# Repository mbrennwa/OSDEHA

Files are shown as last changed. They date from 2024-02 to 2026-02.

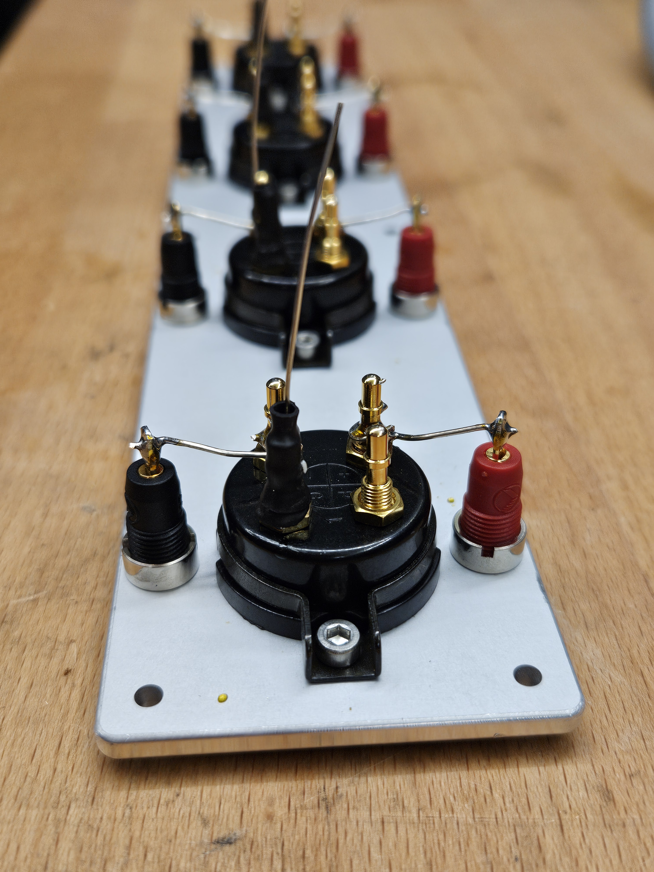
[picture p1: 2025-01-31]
photos/subchassis_underside_sockets1.jpg

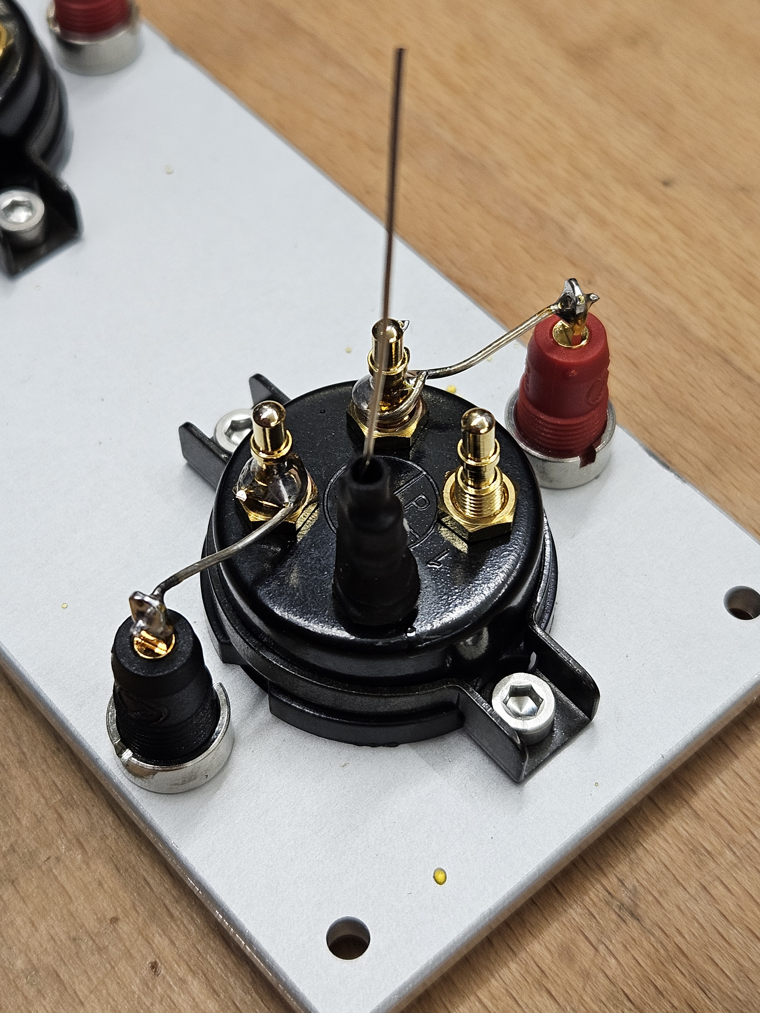
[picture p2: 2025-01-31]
photos/subchassis_underside_sockets2.jpg

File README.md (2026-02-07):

# Open-Source Directly-Heated Triode Electrostatic Headphone Amplifier (OSDEHA)

The OSDEHA is an open-hardware electrostatic headphone amplifier based on directly heated triodes (DHTs).  
It is designed for DIY builders who value simplicity, transparency, and full access to the underlying circuit and mechanical design.

The project is developed openly, with design discussion and iteration happening in the DIY audio community. All design files required to manufacture and assemble the amplifier are provided.

⚠️ **Warning:** This project involves lethal voltages. Do not attempt to build or operate this amplifier unless you understand and respect high-voltage safety practices.

## Documentation & Discussion

- Project homepage:  
  https://mbrennwa.github.io/OSDEHA/

- Design discussion and build feedback:  
  https://www.diyaudio.com/community/threads/open-source-dht-estat-headphone-amp-osdeha.407679/

## License

This project is licensed under the **CERN Open Hardware Licence v2 – Strongly Reciprocal (CERN-OHL-S-2.0)**.

You are free to:
- Study the design  
- Build the hardware  
- Modify and redistribute it  

Under the condition that **derivative works remain open under the same license**.

**Any physical implementation of this design must carry a visible license notice on the outside of the amplifier enclosure**, as required by the CERN-OHL-S-2.0.

See `LICENSE.txt` for details.

## Acknowledgements

Thanks to the diyAudio community for discussion, testing, and feedback during development.

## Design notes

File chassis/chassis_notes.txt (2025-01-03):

Concept:
- 2 chassis (1 x amplifier, 1 x power supply):
	- allows acceptable form factor for amplifier module, while PSU can be hidden away (but PSU can also be stacked underneath the amp).
	- Keep recitifier noise away from amplifier
	- use same footprint (and height?) for both chassis, so they can nicely be stacked or placed next to each other
- Amp dimensions (external, without front plate):
	- width = 280 mm (including 2 x 40 mm width of heatsinks on the sides)
	- height = 100 mm [height not including the power tubes sticking out from the top]
	- depth = 300 mm
- PSU dimensions (external, without front plate):
	- width = 280 mm
	- height = 100 mm [height of large PSU caps 82 mm from PCB]
	- depth = 300 mm
- Connections between PSU and amp:
	- 1 x cable for HV PSU + bias (keep separate from potentially noisy heater / filament RAW DC currents)
	- 1 x cable heater and RAW-DC filament currents (1 x 6.3 VDC for input heaters, 2 x RAW-DC supplies for Coleman Filament regs in the amp chassis)
	- only PSU: IEC mains inlet + switch + fuses
	- only amp: 2 x XLR audio inputs, Stax outputs on frontpanel

Heatsinks for amp:
	- dimensions: 40 x 300 mm x 100 mm
	- Fischer SK 56 100 SA or SK 501 100 SA

PSU inernal arrangement
	- Left: 2 x mains transformers
	- Center: 1 x main PSU board (HV + 6.3 V heater + HV bias)
	- Right: 2 x filament RAW-DC supplies

PSU front panel:
	- Power LED indicator at center

PSU rear panel:
	- IEC mains inlet (incl. switch + fuses), on the side where the mains transformers are
	- 2 x cable connectors to amp chassis

Amp internal arrangment:
	- Heasinks on left and right
	- 2 x amp board on heatsinks.
	  Right board aligned to front plate
	  Left board aligned to rear plate (to keep input tubes away from front plate, make space for Stax connector on front plate)
	- Coleman boards:
	  2 x boards on right, aligned to rear plate
	- 2 x boards boards on left, aligned to front plate (Stax connector on front plate can mount above the Coleman boards)
	- 4 x power tubes between the amp boards, centered on a line in the middle of the chassis. Tubes sticking out on top of the chassis, mounted on small subchassis

Amp front panel:
	- Volume control on right (above right amp board)
	- Stax connector on left (above Coleman regs)
	- Power LED indicator at center

Amp rear panel:
	- 2 x cable connectors to amp chassis
	- 2 x XLR audio inputs

Cable connections between PSU and amp chassis:

	Cable I (high voltage lines):
	- B+
	- B-
	- B2-
	- 580 VDC bias
	- GND
	- Earth/chassis

	Cable II (heater/filament RAW-DC):
	- Heater POS (6.3 V)
	- Heater NEG (0 V) [connected to GND on PSU main board]
	- RAW-DC 1 POS [floating]
	- RAW-DC 1 NEG [floating]
	- RAW-DC 2 POS [floating]
	- RAW-DC 2 NEG [floating]
	cable clamp: 206966-7

	Connector requirements:
	- Use different connectors for the two cables to avoid accidental mixups!
	- PE/chassis connection:
		- PE conncetions on HV cable, not on Filament cable
		- PE/chassis pin on the HV cable must connect before the other pins
	- All connectors must be rated for 600 VDC or more (filament supplies are floating on B- voltage!)
	
	--> Connector HV-Cable: Amphenol DMS 18-8
	    700 V or higher rating
	    center pin is larger/longer, use this for PE -- use extra pins for parallel connections: 2 x PE and 2 x GND between pos and neg HV pins
	    Cable male:     MS3106E18-8P
	    Cable female:   MS3106E18-8S
	    Chassis male:   MS3102E18-8P
	    Chassis female: MS3102E18-8S

	--> Connector Heater/filament cable: DMS 18-12
	    Cable male:     MS3106E18-12P
	    Cable female:   MS3106E18-12S
	    Chassis male:   MS3102E18-12P
	    Chassis female: MS3102E18-12S
	    
	Cable: Lapp 301606S‎, 6 conductors 16 AWG, color coded, shielded

Old notes, but may be worth to keep:

Ideas and thoughts
	- DON'T (EITHER UGLY OR DOES NOT FIT, WILL NEED MACHINING FOR HOLES/PLUGS/VOLUME-KNOB -- FRONTPANEL DESIGN IS EASIER!) Use ready made chassis (19zoll.com, modushop, etc.) or go with separate heatsinks + Schaeffer panels?
	- amp boards on the sides, flat on bottom plate, transistors on heatsinks
	- transformers on the back, on bottom plate (or on rear plate?), between the amp boards
	- PSU boards on the bottom plate, just behind the front plate.
	- RAW DC supply for Coleman regs on rear panel?
	- 4 x power DHTs mounted on sub-chassis above PSU board / transformers
	- Coleman regs near the DHTs on the subchassis for accessibility to adjust filament voltages?
	  ALTERNATIVE: Coleman regs on bottom plate, between amp boards (either near rear or front panel) / 2 Colemans ons left and 2 Colemans on right
	- IEC mains inlet on the rear plate, left side
	- Audio XLR inputs on the rear plate, right side
	- Volume pot (4 channel for balanced/stereo): centered or on the right (away from mains inlet)? Mount pot on subchassis used for DHT output tubes? Use extension rod to the button on the front panel 
	- Headphone jack(s) on front panel, location depending on position of volume control
	- Power indicator LED on front panel, driven by heater supply
	- Front plate covers heat sinks on the sides, plate fixed by four screws into the front edges of the heatsinks (cut threads into heatsinks)
	- Heatsinks fixed to bottom plate with screws, theads cut into lower edge of heatsinks
	- Top and rear plates mounted in between the heatsinks using square alu rods as connectors (about 10x10mm)
	  (top plate connects to the heatsinks, with threaded holes in heatsinks)
	  (reat plate connects to bottom and top plates, so less work messing around with cutting threads in heasinks)

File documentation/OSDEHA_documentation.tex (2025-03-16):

\input{doc_preamble}

\title{The Open-Source Directly-Heated Triode \\ Electrostatic Headphone Amplifier \\ (OSDEHA)}
\author{Matthias Brennwald}
\date{THIS DOCUMENT IS UNDER CONSTRUCTION!\\ Draft Version \today}

\begin{document}

% \twocolumn[\maketitle]

\maketitle

\emph{Warning: This DIY project involves high voltage. Individuals utilizing the information provided must possess expert knowledge, adhere to stringent safety precautions, and assume full responsibility for all associated risks. The authors and contributors of this project expressly disclaim any liability for injuries or damages arising from the use or misuse of this information.}

\clearpage

\tableofcontents

\clearpage

\section{Overview}

This document describes an audio amplifier for electrostatic headphones. The design of the amplifier is targeted at DIY builders and is published as open hardware (see \secn{license}).

Electrostatic headphones operate on audio signals characterized by high voltage and low current. This is the domain of vacuum tubes, making them most suitable as drivers for electrostatic headphones.  While there exist a number of tube amplifiers for electrostatic headphones, many of these designs do not utilize directly-heated triodes (DHTs), which exhibit outstanding linearity and sound quality.\par

The OSDEHA uses DHT tubes for its output stage and implements the following design goals:
\begin{itemize}
\item The audio output is taken directly from the anodes of the DHT output tubes. There are no transformer or capacitors to transfer the power to the headphones.
\item The amplifier input takes balanced input at signal levels of modern audio sources (mostly DACs these days).
\item The design prioritizes the quality of audio reproduction and electronic design rather than on low cost.
\item The amplifier should be reasonably compact. The power supply unit may be a separate unit to keep the amplifier unit reasonable compact.
\end{itemize}

The OSDEHA design files, along with supporting documents and data, are available in the OSDEHA file repository\cite{osdeha_github}.

There is a public discussion thread of the OSDEHA at diyAudio\cite{osdeha_p1}. 

\section{Amplifier Design}

\subsection{Driving Electrostatic Headphones} \seclabel{estat_drive}

Electrostatic headphones operate using three electrodes: two fixed outer electrodes (stators) and a movable central electrode (diaphragm). The diaphragm is biased at a high voltage relative to the stators. The audio signal is applied to the stators in opposite polarities, generating an electric field that controls the movement of the charged diaphragm. For accurate sound reproduction, the electrostatic forces acting on the diaphragm must be proportional to the applied audio signal. To prevent distortion of the audio output, the charge on the diaphragm must remain constant.

The electrical impedance of electrostatic headphones is primarily determined by the capacitance of the two stators, which is typically around \SI{100}{pF}\cite{osdeha_p3}.

The voltage swing required to drive the stators depends on the headphone sensitivity and the desired sound pressure level. An experiment using various genres of well-recorded music indicated that an undistorted \SI{1.3}{kV} peak-to-peak swing of the bipolar output is desirable (i.e., \SI{650}{\unitVpp} at each stator)\cite{osdeha_p8}. The corresponding current swing measured in this experiment was approximately \SI{4}{mA}. However, driving the \SI{100}{pF} load to full output at frequencies up to \SI{20}{kHz} and beyond necessitates larger peak currents, around \SI{20}{mA}\cite{osdeha_p2}.

\subsection{Output Stage}\seclabel{outputstage}

\figr{OPS_concept} illustrates the conceptual layout of the OSDEHA. The output stage employs two DHTs in a push-pull configuration to deliver the symmetric, bipolar output required to drive electrostatic headphones. For efficient audio power transfer to the headphones, the AC impedance of the anode loads must be much larger that that of the headphones (several \unit{M\Ohm}). This cannot be achieved using passive anode-load resistors; instead, active constant-current sources (CCSs) are employed. The CCS loads not only enhance the amplifier's linearity and voltage gain but also suppress ripple and noise from the B+ rails.

\begin{figure}
\begin{center}

\caption{Conceptual layout of the OSDEHA: differential input and gain stage, push-pull DHT output stage.}
\figlabel{OPS_concept}
\end{center}
\end{figure}

The choice of output tube type is dictated by the drive requirements of the headphones, as described in \secn{estat_drive}. Since the two tubes are connected in series with the headphones, each tube is responsible for half of the total voltage swing. Thus, each tube must handle a swing of \SI{\pm325}{V} at a \SI{20}{mA} bias. Furthermore, to emphasize the characteristic ``DHT sound,'' the DHT output stage should contribute as much voltage gain as possible to the overall amplifier gain.

Several DHT tube types were evaluated for the OSDEHA\cite{osdeha_p9,osdeha_whichDHT}. Specifically:

\begin{itemize}
\item The 841/VT-51 tube offers a gain of 30$\times$ and can be biased up to \SI{425}{V}. However, at the operating point required for the OSDEHA, the 841 tends to operate with a positive grid voltage, leading to grid current draw. Additionally, these tubes are relatively scarce.
\item The 20B tube is a modern design with a gain of 20$\times$ and supports biasing up to approximately \SI{500}{V}. However, these tubes are quite large (roughly the size of a beer bottle) and are produced only in small quantities by a single manufacturer (Emissionlabs), raising concerns about their long-term availability.
\item The family of the 801/801A/VT-62 and 10Y/VT-25 types\cite{aasyl_801types} provide a gain of 8$\times$. The 801 can be biased up to \SI{500}{V}, while the 10Y should not be biased above \SI{450}{V}. These tubes are available as new-old-stock and from new production.
\end{itemize}

From a technical perspective, the high gain of the 20B makes it an attractive option. However, due to concerns about the long-term availability of the 20B, the 801/10Y family of tubes is deemed a more practical choice for the OSDEHA design.

\figr{801A_curves} illustrates the characteristic curves measured from the 801A tube (with the 10Y/VT-25 being equivalent) along with the load line of a \SI{20}{mA} constant-current source (CCS). The anode DC bias is set to \SI{420}{V}, corresponding to a grid bias of approximately \SI{-34}{V}. This bias point allows for an anode voltage swing of \SI{\pm325}{V} within the tube's linear operating range. The grid voltage remains below +\SI{10}{V}, where measured grid current stays well under \SI{1}{mA}. With the anode voltage approaching ground potential, the B- voltage is set to \SI{-420}{V} and the B+ voltage to \SI{+420}{V}, maintaining symmetry.

\begin{figure}
\begin{center}

\caption{Characteristic curves of the 801A DHT, showing a DC bias point at \SI{420}{V} and \SI{20}{mA}, with a constant-current load line allowing an anode swing of \SI{\pm325}{V} (blue).}
\figlabel{801A_curves}
\end{center}
\end{figure}

\figr{activeload_concept} shows the simplified circuit of the CCSs used to load the anodes of the DHT output tubes. This circuit functions as a CCS in the audio/AC domain while providing a fixed voltage in the DC domain. In both cases, the FET Q1 controls the circuit's output to the anode. The depletion-mode FET Q2 drops most of the voltage from B+ and isolates Q1 from any noise or ripple present in the B+ supply.\par

\begin{figure}
\begin{center}

\caption{Simplified circuit of the active load (AC-coupled CCS).}
\figlabel{activeload_concept}
\end{center}
\end{figure}

In the audio/AC domain, the gate of Q1 is connected to the anode through capacitor C. Q1 mirrors any AC variation in the anode voltage from its gate to its source pin. This configuration maintains a constant voltage between the source of Q1 and the DHT anode, thereby ensuring a constant current through R2. If the headphone stator is driven directly by the DHT anode (output 1 in \figr{activeload_concept}), this current is shared between the DHT and the stator. Consequently, the current flowing through the DHT will exhibit slight variations in response to the AC current consumed by the stator. These variations are typically less than \SI{4}{mA}\cite{osdeha_p8}, which is significantly smaller than the DC bias current. As a result, the load line seen by the DHT anode will closely resemble the one shown in \figr{801A_curves}, although it may not be perfectly flat. Alternatively, the stator can be connected to the $\mu$-output (output 2 in \figr{activeload_concept}) instead of taking the audio output directly from the DHT anode. In this $\mu$-follower configuration\cite{pimm_ccs,kimmel_mustage}, the stator draws its current directly from Q1 rather than through R2. This restores the constant-current operation of the DHT tube and produces a flat load line as shown in \figr{801A_curves}. The value of R2 is typically chosen as a compromise between maximizing the impedance of the CCS load and minimizing the voltage drop (and heat dissipation) across R2\cite{muresistorvalue}.

In the DC domain, the gate of FET Q1 is grounded through R1, fixing the source pin at $-V_{\rm GS,0}$. This arrangement biases the anode at a slightly negative DC voltage determined by $V_{\rm GS,0}$ and the DC voltage drop across R2. As a result, the amplifier outputs maintain a stable DC voltage, effectively compensating for any thermal drift or aging of the DHT tubes.

\subsection{Input Stage}\seclabel{inputstage}

The primary function of the input stage is to amplify the balanced input signal ($2 \times \SI{3.5}{\unitVpp}$) to a level sufficient to drive the DHT grids ($2 \times \SI{86}{\unitVpp}$). This requires a voltage gain of $86 / 3.5 = 25\times$.

Following the lines of the output stage, the differential input stage is designed as long-tailed pair (LTP)\cite{valvewizard_LTP} utilizing tubes with triode characteristics. To maximize the linearity and voltage gain of the LTP, the ``tail'' is configured as a constant-current source (CCS), as illustrated in \figr{IPS_concept}.

\begin{figure}
\begin{center}

\caption{Simplified circuit of the input stage.}
\figlabel{IPS_concept}
\end{center}
\end{figure}

A triode-connected 6E5P tube provides suitable gain and exhibits very linear amplification\cite{bartola_thdbenchmark,osdeha_p33}. Each 6E5P is biased at \SI{10}{mA} with an anode-to-cathode voltage of \SI{170}{V} and a \SI{25}{k\Ohm} load resistor, providing more than \SI{\pm100}{V} of anode AC swing (\figr{6E5P_curves}).

\begin{figure}
\begin{center}

\caption{Characteristic curves of a triode-connected 6E5P tube, showing a \SI{25}{k\Ohm} load line with DC bias at \SI{170}{V} and \SI{10}{mA}.}
\figlabel{6E5P_curves}
\end{center}
\end{figure}

The LTP input stage is capacitor-coupled to the grids of the output DHTs. A properly chosen capacitor does not introduce measurable distortion to the audio signal\cite{bateman_caps_distortion}, provided there is no significant current flow across it\cite{aiken_farting_out}. To ensure stable biasing, the DHT grids are driven by FETs configured as source followers. The DC bias voltage for the DHT output tubes is applied to the gates of these FETs, ensuring stable operation even when the DHT grids are driven into grid current.

\section{Power Supplies}

\subsection{High-Voltage Supplies (B+, B-, B2-)}
The amplifier's input and output stages operate on a bipolar high-voltage supply (B+ and B- rails). Additionally, the DHT grids require a bias voltage more negative than B-, necessitating an additional B2- supply. All three high-voltage supplies utilize the same circuit design to deliver clean and stable voltage outputs (\figr{HV_PSU_simple}). The circuits are deliberately designed without feedback-based voltage regulation, as such feedback loops are often associated with sound degradation. A full-wave rectifier and smoothing capacitor (C1) generate a raw DC voltage. This raw supply feeds a current source that injects a small, constant current into R1 and C1. Once C1 is fully charged after startup, R1 develops a constant voltage drop, which serves as a reference mirrored to the voltage output across the DC+ and DC- terminals. For the B+ supply, the DC- output is referenced to GND, while the B- and B2- supplies have their DC+ terminals at GND.

\begin{figure}
\begin{center}

\caption{Simplified circuit of the high-voltage power supplies.}
\figlabel{HV_PSU_simple}
\end{center}
\end{figure}

To prevent audio noise during startup and reduce stress on the tubes, the high-voltage supplies are activated only after the tubes have warmed up for a few seconds. This delay is implemented using a relay switch controlled by a timer triggered by the heater supply.

\subsection{Diaphragm Bias Voltage}
High-performance electrostatic headphones typically require a \SI{580}{V} DC bias voltage for the diaphragm. The current output of the bias voltage supply is negligible. A charge pump riding on the B+ rail and its AC supply is used to charge a string of capacitors, with their voltage limited to the intended bias level by a string of Zener diodes in parallel to the capacitors. It is crucial to maintain the \emph{charge} on the diaphragm, rather than the diaphragm voltage. To this end, a high-ohmic current-limiting resistor is inserted in the output of the bias supply.

\subsection{Heater Supply for the Input-Stage Tubes}
The heaters of the input-stage tubes are powered by a clean DC voltage to prevent crosstalk of hum or noise from the heater supply into the audio signal. This DC supply is implemented using a standard three-pin voltage regulator chip.

\subsection{DHT Filament Supply}
Like the input-stage heaters, the DHT filaments are powered by DC. However, in DHTs, the filament also serves as the cathode and is part of the audio circuit. During audio playback, a small signal voltage develops across the filament terminals. To prevent the DC filament supply from interfering with this AC signal, it is preferable to control the filament supply current rather than the voltage. This is accomplished using the Coleman Regulator\cite{ColemanDTHFilReg}. The OSDEHA utilizes four Coleman Regulator V9 boards (one per DHT). In each amplifier channel, a single raw DC supply can power a pair of V9 boards.

\section{Putting the Pieces Together}

\figr{system_overview} provides an overview of the various OSDEHA units and their interconnections. The units are distributed across two chassis: one for the power supply and another for the amplifier.

\begin{figure}
\begin{center}

\caption{Overview of the OSDEHA units and their connections (see text).}
\figlabel{system_overview}
\end{center}
\end{figure}

Power-supply chassis:
\begin{itemize}
\item IEC mains inlet with a power switch and mains fuses
\item Two mains transformers
\item Main power-supply board providing stabilized DC voltages for B+, B-, B2-, diaphragm bias, and the heaters of the input-stage tubes
\item Two boards supplying raw DC to the Coleman DHT filament regulators
\end{itemize}

Amplifier chassis:
\begin{itemize}
\item Two amplifier main boards (left and right channels)
\item Four DHT power tubes (two per channel)
\item Four Coleman DHT filament regulators
\item Two XLR audio input sockets
\item Stereo balanced volume control
\item Stax headphone output socket
\end{itemize}

The two chassis are interconnected by two umbilical cables, U1 and U2. U1 carries the high-voltage, low-current supplies (B+, B-, B2-, GND) and provides the chassis-to-earth connection. U2 carries the low-voltage, high-current supplies for the heaters of the input-stage tubes and the Coleman DHT filament regulators.

\section{Mechanical construction}

HEATSINKS, CHASSIS, ETC.

UMBILICALS BETWEEN PSU AND AMP CHASSIS in \figr{power_pinouts}.

\begin{figure}
\begin{center}

\caption{Pinout of the power umbilical connections between the power supply and amplifier chassis.}
\figlabel{power_pinouts}
\end{center}
\end{figure}

\section{Build Notes, Bring-Up, and Initial Adjustments}

The process of building, testing, and adjusting the OSDEHA is best carried out step by step, as outlined below. Use a variac to gradually ramp up mains power while bringing up the circuits. Turn off the power supply and set the variac output to zero before each step. Before working on the circuits, always ensure that no dangerous voltages remain present (e.g., all capacitors are discharged, and the mains cable is disconnected).

\subsection{Power Supply}
\begin{itemize}
\item Assemble the power-supply chassis and boards. Install the boards, sockets, and transformers in the power-supply chassis. Wire the primary windings of the transformers to the mains inlet and power switch in the chassis. Wire the power supply outputs to the umbilical sockets.
\item Confirm proper connection of all metal parts of the power-supply chassis to mains earth.
\item Wire the transformer secondaries for the heater supply. Switch on the power supply and gradually ramp up mains power using the variac. Confirm that the heater supply functions as expected. Verify the operation of the high-voltage delay relay.
\item Wire the transformer secondaries for the DHT raw-DC filament supplies. Switch on the power supply and gradually ramp up the variac to confirm that the raw-DC supplies function correctly.
\item Wire the transformer secondaries for the high-voltage supplies and install dummy resistors at their outputs. Switch on the power supply and gradually ramp up the variac. Confirm and adjust the high-voltage output levels as needed. Verify the diaphragm bias voltage output (note: the internal resistance of the voltmeter will load the bias output, resulting in a lower voltage reading). Remove the dummy resistors from the high-voltage supplies.
\end{itemize}

\subsection{Amplifier Input Stage}
\begin{itemize}
\item Determine the CCS sense-resistor values that yield the targeted bias currents for the CCSs with the specific DN2540 parts used in the input LTP tail and in the DHT grid drivers (\figr{CCS_Rsense_jig}).
\item Assemble the amplifier chassis, amplifier boards, and Coleman filament regulators. Install the boards and sockets in the amplifier chassis. Install the input-stage tubes, but do \emph{not} install the DHT tubes of the output stages yet. Do \emph{not} yet wire the umbilical sockets to the boards.
\item Install the umbilical cables between the power supply and the amplifier chassis. Wire the amplifier chassis to the earth pins of the umbilical socket. Verify the electrical connection of all metal parts of the amplifier chassis to the power-supply chassis and mains earth. Make sure the XLR pins~1 are connected to the chassis.
\item Wire the heater supply from the umbilical socket to the amplifier boards. Switch on the power supply and gradually ramp up the variac. Verify functioning of the heaters in the input-stage tubes.
\item Wire the high-voltage supplies (B+, B-, B2-) and GND from the umbilical socket to the amplifier boards. Switch on the power supply and gradually ramp up the variac. Verify the correct DC bias of the input-stage tubes (plate voltages and currents) and the DC bias currents of the buffer stages.
\item Wire the audio inputs from the XLR sockets to the volume control and to the amplifier boards. Apply an AC test signal to the XLR sockets and trace the signal path through the circuit, and verify correct output from the buffer stage to the grid pins on the DHT sockets.
\end{itemize}

\begin{figure}
\begin{center}

\caption{Circuit to determine the sense-resistor value $R_{\rm s}$ that yields the desired CCS current for a given DN2540 part. Adjust the $R_{\rm s}$ value until the voltage drop $V_{\rm x}$ across the \SI{100}{\Ohm} resistor corresponds to the desired current.}
\figlabel{CCS_Rsense_jig}
\end{center}
\end{figure}

\subsection{Amplifier Output Stage}
\begin{itemize}
\item With the output tubes still not installed in the amplifier, adjust the grid bias voltage to the most negative value.
\item Disconnect the high-voltage supplies from the amplifier boards. Wire the DHT filament supplies from the umbilical socket to the Coleman filament regulators and to the amplifier boards. Install the DHT output tubes. Switch on the power supply and gradually ramp up the variac while monitoring the DHT filament voltages and paying attention to not exceed the datasheet value. Adjust the filament voltage to the target value. Allow the tubes to warm up and readjust the filament voltage as needed.
\item Reconnect the high-voltage supplies to the amplifier boards, switch on the power supply and gradually ramp up the variac. Monitor the DC bias currents of each output tube by measuring the voltage drop across the mu-resistors. Adjust the DC grid bias until the desired DC bias points are attained. Allow the amplifier to warm up and readjust the DC bias as necessary. Also monitor the filament voltages during warmup and adjust if needed.
\item Apply an AC test signal to the amplifier inputs and verify correct outputs from the amplifier.

\end{itemize}

\section{Specifications and Test Results}

\begin{itemize}
  \item Maximum audio output: \SI{1640}{\unitVpp} into \SI{100}{pF}
  \item Voltage gain: $230 \times$ (\SI{47}{dB})
  \item Input sensitivity for full output: \SI{7}{\unitVpp} (\SI{2.5}{\unitVrms} sine)
  \item Input impedance (balanced): \SI{20}{k\Ohm}
  \item Frequency response with \SI{100}{pF} load (\figr{frequency_response}):\\
        $\mu$-output: \SI{28}{Hz} to \SI{33}{kHz}, $-\SI{0.5}{dB}$\\
        Anode-output: \SI{24}{Hz} to \SI{21}{kHz}, $-\SI{0.5}{dB}$
  \item Crosstalk: $\SI{90}{dB}$ (\SI{1}{kHz})
  \item Harmonic distortion (\figr{harmonics_vs_voltage}): $< \SI{0.04}{\%}$ (\SI{1}{kHz}, \SI{100}{\unitVrms} output)
  % \item Intermodulation Distortion (IMD): see \figr{imd} (use multitone test from REW)
  % \item Power consumption: \SI{XYZ}{W}
\end{itemize}

\begin{figure}
\begin{center}

\caption{Frequency response, measured at \SI{100}{\unitVrms} output with a \SI{100}{pF} load connected to the output.}
\figlabel{frequency_response}
\end{center}
\end{figure}

\begin{figure}
\begin{center}

\caption{Harmonic distortion vs.\ output voltage, measured with a \SI{1}{kHz} fundamental and a \SI{100}{pF} load connected to the $\mu$ output (top) or the anode output (bottom).}
\figlabel{harmonics_vs_voltage}
\end{center}
\end{figure}

\section{Parts List}

The details of most electronic components used in the OSDEHA circuits (tubes, semiconductors, resistors, capacitors) are provided in the KiCad files located in the {\tt kicad/} directory.\cite{osdeha_github} Additional parts, such as chassis, mounting hardware, and connectors, are listed below.

{\footnotesize \csvautobooktabular[separator=tab]{partslist.txt}}

\clearpage
\section{License information} \seclabel{license}
Copyright Matthias Brennwald 2024.                                                    

The OSDEHA is Open Hardware and is licensed under the CERN-OHL-S v2 or any later version.

You may redistribute and modify this source and make products using it under the terms of the CERN-OHL-S v2 (\url{https://ohwr.org/cern_ohl_s_v2.txt}).

This source is distributed WITHOUT ANY EXPRESS OR IMPLIED WARRANTY, INCLUDING OF MERCHANTABILITY, SATISFACTORY QUALITY AND FITNESS FOR A PARTICULAR PURPOSE. Please see the CERN-OHL-S v2 for applicable conditions.

Source location: \url{https://github.com/mbrennwa/OSDEHA}

As per CERN-OHL-S v2 section 4, should You produce hardware based on this source, You must where practicable maintain the Source Location visible on the external case of the OSDEHA or other products you make using this source.            

% list of references
\clearpage
\bibliographystyle{unsrt}
\bibliography{OSDEHA_documentation}

\end{document}

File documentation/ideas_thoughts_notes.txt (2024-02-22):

Overall idea:
Design a high-quality amplifier for electrostatic headphones using directly heated triodes (DHT) in the output stage.

diyAudio thread:
https://www.diyaudio.com/community/threads/open-source-dht-estat-headphone-amp-osdeha.407679

Design targets:
- Use DHT tubes for output stage.
- Priority is on quality of audio reproduction and electronic design rather than on low cost.
- The finished amp should be small enough such that it fits on a desktop.
- The design is intended for use in the DIY community! Avoid the use of unobtanium parts, provide full documentation in a public repository, add a license that allows any use of the design (including commercial) but requires re-publication of any modification or extensions.

General construction
- Design PCB(s) that hold(s) the whole amp (except the tubes and transformers, maybe also PSU can be on separate board to allow people to choose their own PSU). It may make sense to have separate PCBs for LEFT/RIGHT and PSU, but messing with different boards or flying leads for a contraption of many different 3rd party boards/units is ugly.
- Use delay for HV turn on

Input sensitivity, gain, and output voltage level?
- Balanced input (from modern DACs): +/- 4 Vrms = +/- 5.7 Vpk = 11.3 Vpp
- Typical sensitivity for estat headphones is 100 dB-SPL / 100 Vrms.
- Aim for 110...120 dB-SPL peak output without clipping
--> Output voltage needed is 10...20 dB higher than 100 Vrms = 3.16...10 x 100 Vrms = 316...1000 Vrms = 447...1414 Vpk
- Gain needs to be 316...1000 Vrms / 4 Vrms = 79x...250x
- For comparison:
	typical Stax amp: gain=500...1000, max ouput voltage 300...470 Vrms
	Stax T2 amp: gain=1000, max ouput voltage 630 Vrms
	Blue Hawaii: max. output is 1600 Vpp = 800 Vpk = 566 Vrms
--> design target:
- minimum AC output voltage: 600 Vrms / 850 Vpk / 1700 Vpp
- input sensitivity: 4 Vrms / 5.66 Vpk / 11.2 Vpp (balanced input)
- Gain at least 600/4 = 150 (or more)

Ouput current needs, Class-A bias current:
- Basic idea/concept to determine the current draw from estat (but the numbers seem a bit optimistic): https://www.head-case.org/forums/topic/12155-output-stage-current-requirements-for-electrostatic-headphone-amps/
- capacitor (=estat): Q = C x U --> I = dQ/dt = C x dU/dt 
- What is the required dU/dt (slew rate) value?
	- Bob Cordell, Designing Audio Power Ampliers: an amp that produces 40 Vpk output needs slew rate of 12.5 V/µs  to sustain a 50 kHz sine at full power.
	- Nelson Pass 1978 work: "highest slew rate he found with music signals was 1.5 volts/microsecond up to clipping levelsj" (see https://www.head-case.org/forums/topic/12155-output-stage-current-requirements-for-electrostatic-headphone-amps/)
	- Nelson Pass, in a later interview: "...But given that you're on the 5V/µs rate, we ultimately settled on approximately 50V/µs as a speed beyond which was fine, but it became a minimal figure that we deal with in our designs." (this probably referred to a 100W amp driving an 8 Ohm speaker, see https://www.stereophile.com/content/nelson-pass-simple-sounds-better-page-4)
	--> slew-rate numbers required for a 100 W amp driving an 8 Ohm speaker (i.e, 40 Vpk) range from 1.5...50 V/µs.
	--> let's assume 15 V/µs for a 40 Vpk drive
- RMS voltage of a typical estat amp is about 500 Vrms = approx 800 Vpk
--> target slew rate for estat amp: dU/dt = 15 V/µs / 40 Vpk x 800 Vpk = 300 V/µs
--> current needed to charge the estat capacitance the the required slew rate: I = C x dU/dt = 100 pF x 300 V/µs = 30 mA
--> for push-pull amp with 30 mA output: each leg needs to provide 15 mA, so the tubes in each leg must be biased to more than 15 mA for Class-A.

HV bias:
- Stax PRO, Hifiman: 580 VDC
- Stax not-PRO: 2?? VDC
- Warwick Bravura: 1000 VDC

Output stage:
- use similar topology as in Rauenbühler Alpha Centauri amp: two triodes working in opposite polarity, cathodes at negative voltage, anodes biased close to 0 VDC. Output signal is the delta between the two anodes.
- use active loads on the anodes instead of anode load resistors. Simple CCS or (maybe better) an Ale Moglia "Gyrator" / voltage controlled CCS
- use hybrid Mu follower? It's almost the same as a CCS load, but takes the output right from the source pin of the FET in the CCS. The audio signal current therefore does not pass the current-sensing resistor used to fix the current, and the CCS therefore keeps the current into the tube anode constant, while the audio signal current is taken from the FET source pin before it makes its way into the current sensing resistor. In other words, the tube anode sees a constant current, no matter how much current goes into the amplifier output from the FET source pin. Hence, the load line to the tube anode is perfectly flat.
- Advantage of the Moglia Gyrator CCS: it allows adjusting the DC idle voltage at the anodes. The Moglia Gyrator then fixes the current to the operating point corresponding to the chosen DC bias voltage, and the AC/audio signals are operating at this fixed current with variable audio/AC voltage. The adjustabililty of the DC anode voltage means that both triodes can be adjusted to the same DC anode potential, and hence the DC imbalance between the two triodes can be adjusted and fixed to 0 V.
- Two Moglia Gyrators set the DC voltage based on a small CCS voltage reference that is adjusted with a trimpot. The Moglia Gyrators used for the opposite polarity tubes could use the same voltage reference, so the DC voltage at both tubes would automatically be the same.
- output tubes 801A are biased such that they are driven into slightly positive grid voltage (Class A2) at full swing. The prevent drop of the grid voltage due to grid current through the grid stopper resistor, the grid stopper resistor value should be as low as possible, and maybe even zero. This may need some experimentation in the prototype to check for oscillation.

DHT Triode type for use in output stage
- For 600 Vrms / 850 Vpk output: every tube needs to swing +/- 850/2 = 425 Vpk
- Should be okay with slightly high(er) voltage peaks beyond it's own active drive (reactance of the capacitive headphones?)
- DC current bias 20 mA or more (to provide substantial headroom to properly drive the headphones)
- Use something that is available (either new production or plenty old stock available)
- 801(A) tubes seem about right (NOS available, Elrog makes 801A tubes). 801A gain is 8x, so the input/driver stage needs gain of at least 19x (and some more to provide for NFB maybe).
- Emissionlabs 20B tube maybe? EML has whacky reputation, and there is no other manufactured that has similar specs -- is this future proof? 20B has gain of 20x, so input stage needs gain of at least 7.5 (and some more to provide for NFB maybe?).
- DOES NOT WORK: 841 tube has 30x gain, but: Vgrid=0 and Ia=20ma --> Vanode = 520 V --> Vanode_bias = 520 V + 425 V = 945 V bias just to allow the 425 V swing. That's A LOT! 925 V x 20 mA = 18.5, which is higher than the allowed plate dissipation Pa = 12 Watt

Input stage
- can be tube or FET or BJT
- Ale Moglia THD benchmark: https://www.bartola.co.uk/valves/2012/06/17/thd-benchmark/
- Pete Millett looked at some pentodes configured as triodes, measured gain and linearity (12HL7!!): http://www.pmillett.com/pentodes.htm
- Some tubes, indirectly heated: use very linear tube! 6SN7 (gain=20), ECC88 (gain=33), 6N30P (gain=14), 6N5P (gain=24), D3A-triode (gain=77)
- Some tubes, directly heated: 3C4/DL96 (gain=8, https://www.diyaudio.com/community/threads/designing-a-vacuum-tube-front-end-card-for-the-vfet-diy-amp.371158/page-9)
- for 801 output tubes (gain=8): gain required for input tube is 19x --> 6N30P is too low (except maybe for folded cascode, see below)
- for 20B output tubes (gain=20): gain required for input stage is 7.5x --> could work with 3C4/DL96 gain, but this tube would surely need a buffer/powerdrive FET.
- Some interesting tubes: https://www.bartola.co.uk/valves/tag/6e6p-e/
- 6E5P and 6E6P stuff: https://www.bartola.co.uk/valves/2013/02/18/6e5p6%d1%8d5%d0%bf-and-6e6p-e6%d1%8d6%d0%bf-e-in-triode-mode/
- 6E6P: "Unfortunately the variance of the valve’s parameters is all over the place" https://www.bartola.co.uk/valves/2022/10/30/6e6p-dr-curves-6%d1%8d6%d0%bf-%d0%b4%d1%80/
- More Moglia stuff on input/driver tubes: https://www.bartola.co.uk/valves/2018/04/01/driving-hard-part-i/
- Shunt-cascode / folded cascode tube/BJT input+driver (vertical load line on tube anode! great with 6E5P, not great with DHTs, see below): high gain, low distortion!
	- See https://www.bartola.co.uk/valves/2013/03/10/the-shunt-cascode-driver/
	- Also, see here for a discussion why DHTs may not be ideal for this, while a 6E5p is great: https://www.bartola.co.uk/valves/2019/07/01/dht-folded-cascode-experiments/

HV Power supply:
- Take a look at Jan Diddnes T-Reg at https://diyaudiostore.com/collections/kits/products/linear-audio-t-reg
  Jan Didden by PM on diyAudio: "if you have two isolated secondaries on your transformer (or two transformers), you can use two T-regs in series. Connect the output of one to ground and its ground becomes a negative voltage. Works fine but the two supplies should be totally independent with separate secondaries. Jan"
- There is also a high voltage PSU delay by Jan Didden: https://diyaudiostore.com/collections/kits/products/high-voltage-delay-for-tube-amplifiers
- Pete Millett HV PSU with time delay: http://www.pmillett.com/mec_power_supply_delay.html
- SALAS SSHV2: https://www.diyaudio.com/community/threads/simplistic-mosfet-hv-shunt-regs.134801/
- Maida HV PSU
- ***** Moglia HV (stabilized on CCS voltage reference, but not regulated by feedback from output): https://www.bartola.co.uk/valves/2015/01/10/popping-the-shunt-voltage-regulators-clogs/#more-4301

DHT filament supply:
- Rod Coleman. https://lyrima.co.uk/pdf/AN-DHT-V7-2.pdf
- For 801 / 10Y / VT25 tubes: 7.5 V @ 1.25 A each
- Coleman reg needs 10.1...11.2 VDC input from raw DC supply
- Duncan PSUD2 model with C-R+R-C filter:
	- Rectifier = 4 x 1N5822
	- C = 15'000 uF
	- R = 0.22 Ohm
	- Assume 4.5 A transformer with approx. 45-50 VA, which has estimated primary source resistance of 80 Ohm
	- reflected secondary source resistance = 0.136 Ohm
	- Current draw per channel = 2 x 1.25 A (2 x 801 tube)
	--> PSUD2 calculator shows 10.2 VDC output with +/- 0.1 V ripple for a secondary voltage of 10.0 VAC(rms), so voltage is always 10.1 V or higher (as needed for Coleman reg.)
	--> Allow AC mains to be 5% lower than nominal, so nominal secondary AC voltage must be at least 10.0/0.95 = 10.5 VAC(rms)
	==> Transformer secondary specificiation (per channel): 10.5 VAC / 4.5 A

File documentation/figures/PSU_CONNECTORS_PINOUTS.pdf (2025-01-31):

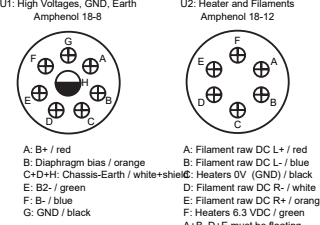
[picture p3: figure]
A: Filament raw DC L+ / red B: Filament raw DC L- / blue C: Heaters 0V (GND) / black; A: B+ / red B: Diaphragm bias / orange C+D+H: Chassis-Earth / white+shield E: B2- / green F: B- / blue G: GND / black; U2: Heater and Filaments Amphenol 18-12; U1: High Voltages, GND, Earth Amphenol 18-8

D: Filament raw DC R- / white E: Filament raw DC R+ / orange F: Heaters 6.3 VDC / green A+B, D+E must be floating

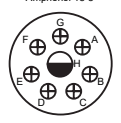
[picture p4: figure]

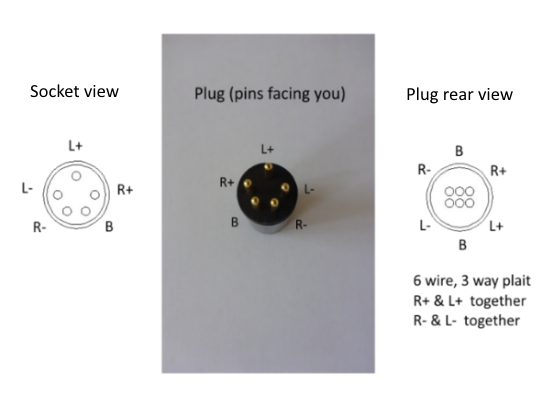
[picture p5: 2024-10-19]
datasheets/stax_plug_pinout.PNG

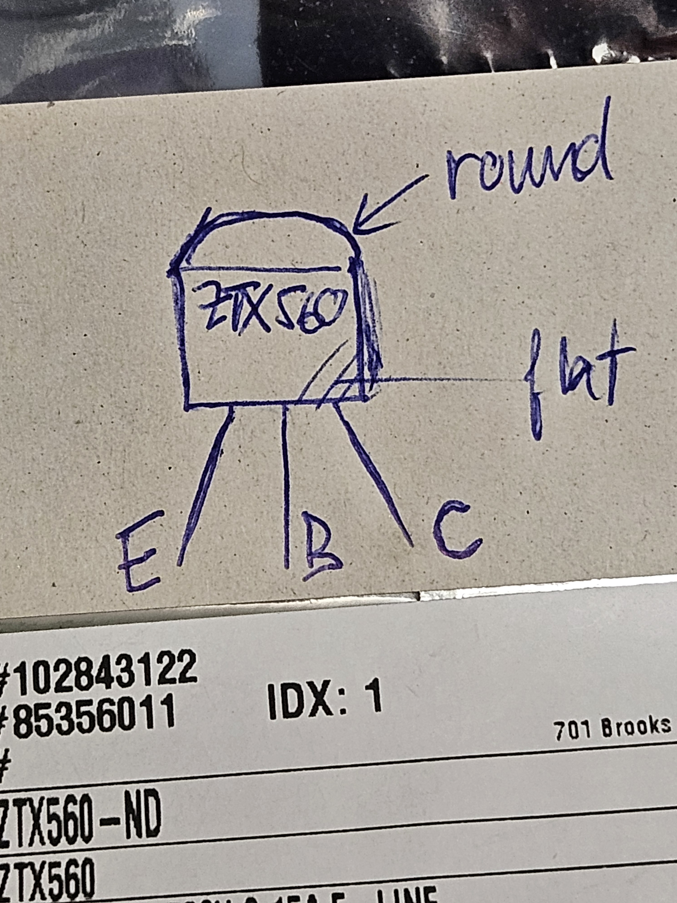
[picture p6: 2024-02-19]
datasheets/ZTX560_pinout.jpg

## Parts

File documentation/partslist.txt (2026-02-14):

Part Description	Number	Manufacturer	MPN and Details
UX4 tube sockets	4	(various)	sub-chassis mount
Noval tube sockets	4	(various)	PCB mount
Stepped attenuator	1	Goldpoint	 4 channels, 10\,k\Ohm\ per channel, 47 positions
Volume knob	1	Custom made	59\,mm diameter, for 6\,mm shaft
Heatsinks 300$\times$100$\times$40\	mm	2	Fischer	SK 56 100 SA
Amplifier front panel	1	Front Panel Express	file {\tt OSDEHA\_AMP\_front.fpd}
Amplifier top panel	1	Front Panel Express	file {\tt OSDEHA\_AMP\_top.fpd}
Amplifier rear panel	1	Front Panel Express	file {\tt OSDEHA\_AMP\_rear.fpd}
Amplifier bottom panel	1	Front Panel Express	file {\tt OSDEHA\_AMP\_bottom.fpd}
Amplifier DHT subchassis panel	1	Front Panel Express	file {\tt OSDEHA\_AMP\_subchassis.fpd}
Power supply front panel	1	Front Panel Express	
Power supply top panel	1	Front Panel Express	
Power supply rear panel	1	Front Panel Express	
Power supply bottom panel	1	Front Panel Express	
Power supply side panels	2	Front Panel Express
Chassis panel joints		n/a	10$\times$10\	mm aluminium rods
Chassis feet	8	(various)	
XLR input socket	2	Neutrik	NC3FD-L-B-1, 3 contacts, female
IEC mains inlet	1	Schurter	KM00.1105.11
IEC mains inlet fuse holder	1	Schurter	4301.1401
Mains fuse	2		5$\times$20\,mm
Mains transformer (HV)	1	Toroidy	2$\times$350\,VAC / 200\,mA, 1$\times$420\,VAC / 70\,mA
Mains transformer (HTR+FIL)	1	Toroidy	2$\times$9.5\,VAC / 4.5\,A, 1$\times$9\,VAC / 4.5\,A
Power supply outlet socket (HV)	1	Amphenol	MS3102E18-8S
Amplifier power socket (HV)	1	Amphenol	MS3102E18-8P
Umbilical connector (HV/PSU)	1	Amphenol	MS3106E18-8P
Umbilical connector (HV/AMP)	1	Amphenol	MS3106E18-8S
Power supply outlet socket (F+H)	1	Amphenol	MS3102E18-12S
Amplifier power socket (F+H)	1	Amphenol	MS3102E18-12P
Umbilical connector (F+H/PSU)	1	Amphenol	MS3106E18-12P
Umbilical connector (F+H/AMP)	1	Amphenol	MS3106E18-12S
Umbilical wires	2	Lapp	301606S
Power indicator LEDs	2	Vishay	VLHW5100 (or other 5\,mm white LED)
Power indicator LEDs, resistors	2	Vishay	CMF55200R (for connection to 6.3\,V heaters)
Screw terminals	4	Phoenix Contact	1729128 (Filemant regulator boards)
Test sockets for DHT filaments	8	Alltech	975455700
Standoffs, metal, M3$\times$8\,mm	20	Hasler	83.2220.03008 / PCBs
Standoffs, metal, M3$\times$30\,mm	6	Hasler	83.2220.03030 / Subchassis
Allen screws M4$\times$12\,mm	?	Hasler	83.1215.04012 / Panels to chassis joints and heatsink
Headless screw M4$\times$16\,mm	?	Hasler	83.1705.04016 / Front panel to heatsink
Allen screws M4$\times$18\,mm	?	Hasler	83.1215.04018 / Chassis joints to heatsinks
Allen screws M4$\times$12\,mm, flat head	20	Hasler	83.1270.04012 / Top and rear panel
Allen screws M3$\times$5\,mm	?	Hasler	83.1215.03005 / PCBs to standoffs
Allen screws M3$\times$5\,mm	8	Hasler	83.1215.03005 / DHT sockets to subchassis
Allen screws M3$\times$6\,mm	?	Hasler	83.1215.03006 / Standoffs to bottom panel
Allen screws M3$\times$8\,mm	14	Hasler	83.1215.03008 / Transistors to heatsinks
Shoulder washers, for TO-220	?	Essentra	10SC004004, insulator washer
Shoulder washers, for TO-247	?	???	???, insulator washer
Heat spreader, for TO-220	?	T-Global	XL25W-TO220-18.5-12-1
Heat spreader, for TO-247	?	T-Global	XL25W-TO247-22-17-1
KK-396 pigtail cable, 2 pin	?	Molex	219665-1024
KK-396 pigtail cable, 3 pin	?	Molex	219665-1034
KK-396 pigtail cable, 4 pin	?	Molex	219665-1044

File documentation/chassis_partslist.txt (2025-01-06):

Part Description	Number	Manufacturer	MPN / Details
UX4 tube sockets	4	(various)	sub-chassis mount
Noval tube sockets	4	(various)	PCB mount
Stepped attenuator	1	Goldpoint	 4 channels, 10\,k\Ohm\ per channel, 47 positions
Volume knob	1	Custom made	59\,mm diameter, for 6\,mm shaft
Heatsinks 300$\times$100$\times$40\	mm	2	Fischer	SK 56 100 SA
Amplifier front panel	1	Front Panel Express	file {\tt OSDEHA\_AMP\_front.fpd}
Amplifier top panel	1	Front Panel Express	file {\tt OSDEHA\_AMP\_top.fpd}
Amplifier rear panel	1	Front Panel Express	file {\tt OSDEHA\_AMP\_rear.fpd}
Amplifier bottom panel	1	Front Panel Express	file {\tt OSDEHA\_AMP\_bottom.fpd}
Amplifier DHT subchassis panel	1	Front Panel Express	file {\tt OSDEHA\_AMP\_subchassis.fpd}
Power supply front panel	1	Front Panel Express	
Power supply top panel	1	Front Panel Express	
Power supply rear panel	1	Front Panel Express	
Power supply bottom panel	1	Front Panel Express	
Power supply side panels	2	Front Panel Express	
Chassis panel joints		n/a	10$\times$10\	mm aluminium rods
Chassis feet	8	(various)	
IEC mains inlet	1	Schurter	KM01.1205.11
IEC mains inlet fuse holder	1	Schurter	4301.1401
Power supply outlet socket (HV)	1	Amphenol	MS3102E18-8S
Amplifier power socket (HV)	1	Amphenol	MS3102E18-8P
Umbilical connector (HV/PSU)	1	Amphenol	MS3106E18-8P
Umbilical connector (HV/AMP)	1	Amphenol	MS3106E18-8S
Power supply outlet socket (F+H)	1	Amphenol	MS3102E18-12S
Amplifier power socket (F+H)	1	Amphenol	MS3102E18-12P
Umbilical connector (F+H/PSU)	1	Amphenol	MS3106E18-12P
Umbilical connector (F+H/AMP)	1	Amphenol	MS3106E18-12S
Umbilical wires	2	Lapp	301606S
Standoffs (PCBs)		Keystone	24400 (or similar 5\,mm / M3 full-metal part)
Standoffs (sub chassis)		Würth	970300474 (or similar 30\,mm / M4 full metal part)
Test sockets for DHT filaments	8	Alltech	975455700

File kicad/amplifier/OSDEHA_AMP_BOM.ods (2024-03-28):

# | Reference | Qty | Value | MPN | Footprint | DNP
1 | C1, C4, C5, C6, C7, C8, C9 | 7 | 220n 630 V | MKP4J032204J00KSSD | Capacitor_THT:C_Rect_L18.0mm_W9.0mm_P15.00mm_FKS3_FKP3
2 | C2, C3 | 2 | 470n 1 kV | MKP1J034706B00JYSD | Capacitor_THT:C_Rect_L31.5mm_W13.0mm_P27.50mm_MKS4
3 | D3, D4, D5, D6, D7, D8, D9, D10 | 8 | 15V | ZY15 | Diode_THT:D_DO-41_SOD81_P7.62mm_Horizontal
4 | H1, H2, H3, H4 | 4 | MountingHole | -- | MountingHole:MountingHole_3.2mm_M3
5 | J1 | 1 | INPUT | 41791-0849 | Connector_Molex:Molex_KK-396_A-41791-0002_1x02_P3.96mm_Vertical
6 | J2 | 1 | HEATERS DC | 41791-0849 | Connector_Molex:Molex_KK-396_A-41791-0002_1x02_P3.96mm_Vertical
7 | J3 | 1 | PSU HV | 41791-0851 | Connector_Molex:Molex_KK-396_A-41791-0004_1x04_P3.96mm_Vertical
8 | J4 | 1 | OUTPUT | 41791-0849 | Connector_Molex:Molex_KK-396_A-41791-0002_1x02_P3.96mm_Vertical
9 | J5 | 1 | DHT FIL2 | 41791-0849 | Connector_Molex:Molex_KK-396_A-41791-0002_1x02_P3.96mm_Vertical
10 | J6 | 1 | DHT FIL1 | 41791-0849 | Connector_Molex:Molex_KK-396_A-41791-0002_1x02_P3.96mm_Vertical
11 | Q1, Q2, Q9, Q10 | 4 | DN2540N5-G | DN2540N5-G | Package_TO_SOT_THT:TO-220-3_Vertical
12 | Q3, Q4 | 2 | STF3LN80K5 | STF3LN80K5 | Package_TO_SOT_THT:TO-220-3_Vertical
13 | Q5, Q7 | 2 | AOT1N60 | AOT1N60 | Package_TO_SOT_THT:TO-220-3_Vertical
14 | Q6, Q8 | 2 | IXTP3N100D2 | IXTP3N100D2 | Package_TO_SOT_THT:TO-220-3_Vertical
16 | R1, R3 | 2 | 500k | CMF55500K00 | Resistor_THT:R_Axial_DIN0207_L6.3mm_D2.5mm_P10.16mm_Horizontal
17 | R2, R7, R21, R22 | 4 | 1k | CMF551K0000 | Resistor_THT:R_Axial_DIN0207_L6.3mm_D2.5mm_P10.16mm_Horizontal
18 | R4, R9 | 2 | 27.4k 5W | 85F27K4 REPLACE WITH VISHAY PART? | Resistor_THT:R_Radial_Power_L16.1mm_W9.0mm_P7.37mm
19 | R5, R8, R34, R39, R40, R42 | 6 | 300 | CMF55300R00 | Resistor_THT:R_Axial_DIN0207_L6.3mm_D2.5mm_P10.16mm_Horizontal
20 | R6 | 1 | 75 | CMF5575R000 | Resistor_THT:R_Axial_DIN0207_L6.3mm_D2.5mm_P10.16mm_Horizontal
21 | R10 | 1 | 12k 7W | AC07000001202JAC00 | Resistor_THT:R_Radial_Power_L16.1mm_W9.0mm_P7.37mm
22 | R11, R13, R16, R18 | 4 | 1M | CMF551M0000 | Resistor_THT:R_Axial_DIN0207_L6.3mm_D2.5mm_P10.16mm_Horizontal
23 | R12, R17 | 2 | 47k | CMF5547K000 | Resistor_THT:R_Axial_DIN0207_L6.3mm_D2.5mm_P10.16mm_Horizontal
24 | R14, R19 | 2 | 20k | 3296W-1-203 | Potentiometer_THT:Potentiometer_Bourns_3296W_Vertical
25 | R15, R20 | 2 | 25k | CMF5525K000 | Resistor_THT:R_Axial_DIN0207_L6.3mm_D2.5mm_P10.16mm_Horizontal
26 | R27, R28, R44, R45, R46, R47, R48, R49 | 8 | 1.27k | CMF551k2700 | Resistor_THT:R_Axial_DIN0207_L6.3mm_D2.5mm_P2.54mm_Vertical
27 | R30, R31, R32, R35, R36, R37 | 6 | 1.5M | CMF551M5000 | Resistor_THT:R_Axial_DIN0207_L6.3mm_D2.5mm_P10.16mm_Horizontal
28 | R33, R38 | 2 | 470 | CMF55470R00 | Resistor_THT:R_Axial_DIN0207_L6.3mm_D2.5mm_P10.16mm_Horizontal
29 | R41, R43 | 2 | 150 | CMF55150R00 | Resistor_THT:R_Axial_DIN0207_L6.3mm_D2.5mm_P10.16mm_Horizontal
30 | SW1 | 1 | SW_DPDT_x2 | TMD1T5B2M2RE | OSDEHA_AMP:SWITCH_2POLE_ON_ON
31 | U1, U2 | 2 | 6E5P |  | OSDEHA_AMP:belton_noval-bside
32 | U3, U4 | 2 | 801A |  | Connector_Molex:Molex_KK-396_A-41791-0004_1x04_P3.96mm_Vertical

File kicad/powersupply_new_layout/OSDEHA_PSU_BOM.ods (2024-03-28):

# | Reference | Qty | Value | MPN | Footprint | DNP
1 | C1, C2 | 2 | 470u 550 VDC | ALH82A471DL550 | Capacitor_THT:CP_Radial_D35.0mm_P10.00mm_SnapIn
2 | C3 | 1 | 220u 630 VDC | ALC70A221DE630 | Capacitor_THT:CP_Radial_D35.0mm_P10.00mm_SnapIn
3 | C4 | 1 | 10000u 25 V | ALC80A103BB025 | Capacitor_THT:CP_Radial_D25.0mm_P10.00mm_SnapIn
4 | C5, C6, C9, C10 | 4 | 100n 1 kV | MKP4O131004J00KSSD | Capacitor_THT:C_Rect_L18.0mm_W9.0mm_P15.00mm_FKS3_FKP3
5 | C7, C8 | 2 | 22u 16 V | 860160372003 | Capacitor_THT:CP_Radial_D5.0mm_P2.00mm
6 | C11 | 1 | 100n | F881DH104M300L | Capacitor_THT:C_Rect_L26.5mm_W8.5mm_P22.50mm_MKS4
7 | C12, C13, C14 | 3 | 4.7u 630 V | MKP4J044707G00KSSD | Capacitor_THT:C_Rect_L41.5mm_W20.0mm_P37.50mm_MKS4
8 | CHASSIS1 | 1 | MountingHole_Pad | -- | MountingHole:MountingHole_3.2mm_M3_Pad
9 | D1, D2, D3, D4 | 4 | SBT1845-3G | SBT1845-3G | Package_TO_SOT_THT:TO-220-2_Vertical
10 | D5, D7 | 2 | 1N4007 | 1N4007 | Diode_THT:D_DO-41_SOD81_P7.62mm_Horizontal
11 | D6 | 1 | 1N4004 | 1N4004 | Diode_THT:D_DO-41_SOD81_P10.16mm_Horizontal
12 | D8, D9 | 2 | 200 V | ZY200 | Diode_THT:D_DO-41_SOD81_P7.62mm_Horizontal
13 | D10 | 1 | 180 V | ZY180 | Diode_THT:D_DO-41_SOD81_P7.62mm_Horizontal
14 | D11 | 1 | GBJ3510 | GBJ3510_T0_00601 | Diode_THT:Diode_Bridge_32.0x5.6x17.0mm_P10.0mm_P7.5mm
15 | D12, D13, D14, D15, D16, D17, D18, D19, D20, D21, D22, D23 | 12 | STTH512FP | STTH512FP | Package_TO_SOT_THT:TO-220-2_Vertical
16 | H1, H2, H3 | 3 | MountingHole | -- | MountingHole:MountingHole_3.2mm_M3
17 | J1, J2 | 2 | 340 VAC / 220 mA | 1729128 | TerminalBlock_Phoenix:TerminalBlock_Phoenix_MKDS-1,5-2-5.08_1x02_P5.08mm_Horizontal
18 | J3 | 1 | 420 VAC / 75 mA | 1729128 | TerminalBlock_Phoenix:TerminalBlock_Phoenix_MKDS-1,5-2-5.08_1x02_P5.08mm_Horizontal
19 | J4 | 1 | 9 VAC / 4.5 A | 1729128 | TerminalBlock_Phoenix:TerminalBlock_Phoenix_MKDS-1,5-2-5.08_1x02_P5.08mm_Horizontal
20 | J5 | 1 | Stator bias |  | Connector_Molex:Molex_KK-396_A-41791-0002_1x02_P3.96mm_Vertical
21 | J6 | 1 | HV-L |  | Connector_Molex:Molex_KK-396_A-41791-0004_1x04_P3.96mm_Vertical
22 | J7 | 1 | HV-R |  | Connector_Molex:Molex_KK-396_A-41791-0004_1x04_P3.96mm_Vertical
23 | J8 | 1 | HEATERS-LEFT |  | Connector_Molex:Molex_KK-396_A-41791-0002_1x02_P3.96mm_Vertical
24 | J9 | 1 | HEATERS-RIGHT |  | Connector_Molex:Molex_KK-396_A-41791-0002_1x02_P3.96mm_Vertical
25 | K1 | 1 | RT424006 | RT424006 | Relay_THT:Relay_DPDT_Schrack-RT2-FormC_RM5mm
26 | Q1 | 1 | BD138 |  | Package_TO_SOT_THT:TO-126-3_Vertical
27 | Q2 | 1 | 10M90S | IXCP10M90S | Package_TO_SOT_THT:TO-220-3_Vertical
28 | Q3, Q4, Q7, Q8, Q11, Q12 | 6 | LND150 | LND150N3-G | Package_TO_SOT_THT:TO-92
29 | Q5, Q9, Q13 | 3 | NTHL1000N170M1 | NTHL1000N170M1 | Package_TO_SOT_THT:TO-247-3_Vertical
30 | Q6, Q10, Q14 | 3 | BC550 |  | Package_TO_SOT_THT:TO-92_Inline
31 | R1, R2 | 2 | 787k | CMF55787K00 | Resistor_THT:R_Axial_DIN0207_L6.3mm_D2.5mm_P10.16mm_Horizontal
32 | R3 | 1 | 976k | CMF55976K00 | Resistor_THT:R_Axial_DIN0207_L6.3mm_D2.5mm_P10.16mm_Horizontal
33 | R4 | 1 | 10k | CMF5510K000 | Resistor_THT:R_Axial_DIN0207_L6.3mm_D2.5mm_P2.54mm_Vertical
34 | R5 | 1 | 47k |  | Resistor_THT:R_Axial_DIN0207_L6.3mm_D2.5mm_P2.54mm_Vertical
35 | R6 | 1 | 787k | CMF55787K00 | Resistor_THT:R_Axial_DIN0207_L6.3mm_D2.5mm_P2.54mm_Vertical
36 | R7 | 1 | 1.91k | CMF551K9100 | Resistor_THT:R_Axial_DIN0207_L6.3mm_D2.5mm_P10.16mm_Horizontal
37 | R8 | 1 | 470 | CMF55470R00 | Resistor_THT:R_Axial_DIN0207_L6.3mm_D2.5mm_P10.16mm_Horizontal
38 | R9 | 1 | 3.3k |  | Resistor_THT:R_Axial_DIN0207_L6.3mm_D2.5mm_P10.16mm_Horizontal
39 | R10 | 1 | 2k | CMF552K0000 | Resistor_THT:R_Axial_DIN0207_L6.3mm_D2.5mm_P10.16mm_Horizontal
40 | R11 | 1 | 3k | CMF553K0000 | Resistor_THT:R_Axial_DIN0207_L6.3mm_D2.5mm_P2.54mm_Vertical
41 | R12, R13 | 2 | 100k | CMF55100K00 | Resistor_THT:R_Axial_DIN0207_L6.3mm_D2.5mm_P2.54mm_Vertical
42 | R14 | 1 | 4.7M | CMF554M7000 | Resistor_THT:R_Axial_DIN0207_L6.3mm_D2.5mm_P10.16mm_Horizontal
43 | R15 | 1 | 100 5 W | AC05AT0001000JAC00 | Resistor_THT:R_Axial_DIN0918_L18.0mm_D9.0mm_P22.86mm_Horizontal
44 | R16, R22, R28 | 3 | 1M | CMF551M0000 | Resistor_THT:R_Axial_DIN0207_L6.3mm_D2.5mm_P10.16mm_Horizontal
45 | R17, R19, R23, R25, R29, R31 | 6 | 1k |  | Resistor_THT:R_Axial_DIN0207_L6.3mm_D2.5mm_P10.16mm_Horizontal
46 | R18, R24, R30 | 3 | 1.5k | CMF551K5000 | Resistor_THT:R_Axial_DIN0207_L6.3mm_D2.5mm_P10.16mm_Horizontal
47 | R20, R26, R32 | 3 | 300 | CMF55300R00 | Resistor_THT:R_Axial_DIN0207_L6.3mm_D2.5mm_P10.16mm_Horizontal
48 | R21, R27, R33 | 3 | 2 | CMF552R0000 | Resistor_THT:R_Axial_DIN0207_L6.3mm_D2.5mm_P10.16mm_Horizontal
49 | RV1 | 1 | 1M | 3296W-1-105 | Potentiometer_THT:Potentiometer_Bourns_3296W_Vertical
50 | RV2, RV3, RV4 | 3 | 1k | 3296W-1-102 | Potentiometer_THT:Potentiometer_Bourns_3296W_Vertical
51 | U1 | 1 | LM1085-ADJ | LM1085IT-ADJ/NOPB | Package_TO_SOT_THT:TO-220-3_Vertical
52 | U2 | 1 | NE555P | NE555P | Package_DIP:DIP-8_W7.62mm

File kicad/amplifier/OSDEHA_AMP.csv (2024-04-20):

# | Reference | Qty | Value | Footprint | DNP
1 | C1, C4, C5, C6, C7, C8, C9 | 7 | 220n 630 V | Capacitor_THT:C_Rect_L18.0mm_W9.0mm_P15.00mm_FKS3_FKP3
2 | C2, C3 | 2 | 470n 1 kV | Capacitor_THT:C_Rect_L31.5mm_W13.0mm_P27.50mm_MKS4
3 | D3, D4, D5, D6, D7, D8, D9, D10 | 8 | 15V | Diode_THT:D_DO-41_SOD81_P7.62mm_Horizontal
4 | H1, H2, H3, H4 | 4 | MountingHole | MountingHole:MountingHole_3.2mm_M3
5 | J1 | 1 | INPUT | Connector_Molex:Molex_KK-396_A-41791-0002_1x02_P3.96mm_Vertical
6 | J2 | 1 | HEATERS DC | Connector_Molex:Molex_KK-396_A-41791-0002_1x02_P3.96mm_Vertical
7 | J3 | 1 | PSU HV | Connector_Molex:Molex_KK-396_A-41791-0004_1x04_P3.96mm_Vertical
8 | J4 | 1 | OUTPUT | Connector_Molex:Molex_KK-396_A-41791-0002_1x02_P3.96mm_Vertical
9 | J5 | 1 | DHT FIL2 | Connector_Molex:Molex_KK-396_A-41791-0002_1x02_P3.96mm_Vertical
10 | J6 | 1 | DHT FIL1 | Connector_Molex:Molex_KK-396_A-41791-0002_1x02_P3.96mm_Vertical
11 | Q1, Q2 | 2 | DN2540N5-G | Package_TO_SOT_THT:TO-220-3_Vertical
12 | Q3, Q4 | 2 | STF3LN80K5 | Package_TO_SOT_THT:TO-220-3_Vertical
13 | Q5, Q7 | 2 | AOT1N60 | Package_TO_SOT_THT:TO-220-3_Vertical
14 | Q6, Q8 | 2 | IXTP3N100D2 | Package_TO_SOT_THT:TO-220-3_Vertical
15 | Q9, Q10 | 2 | DN2540 | Package_TO_SOT_THT:TO-220-3_Vertical
16 | R1, R3 | 2 | 500k | Resistor_THT:R_Axial_DIN0207_L6.3mm_D2.5mm_P10.16mm_Horizontal
17 | R2, R7, R21, R22 | 4 | 1k | Resistor_THT:R_Axial_DIN0207_L6.3mm_D2.5mm_P10.16mm_Horizontal
18 | R4, R9 | 2 | 27.4k 5W | Resistor_THT:R_Radial_Power_L16.1mm_W9.0mm_P7.37mm
19 | R5, R8, R34, R39, R40, R42 | 6 | 300 | Resistor_THT:R_Axial_DIN0207_L6.3mm_D2.5mm_P10.16mm_Horizontal
20 | R6 | 1 | 75 | Resistor_THT:R_Axial_DIN0207_L6.3mm_D2.5mm_P10.16mm_Horizontal
21 | R10 | 1 | 12k 7W | Resistor_THT:R_Radial_Power_L16.1mm_W9.0mm_P7.37mm
22 | R11, R13, R16, R18 | 4 | 1M | Resistor_THT:R_Axial_DIN0207_L6.3mm_D2.5mm_P10.16mm_Horizontal
23 | R12, R17 | 2 | 47k | Resistor_THT:R_Axial_DIN0207_L6.3mm_D2.5mm_P10.16mm_Horizontal
24 | R14, R19 | 2 | 20k | Potentiometer_THT:Potentiometer_Bourns_3296W_Vertical
25 | R15, R20 | 2 | 25k | Resistor_THT:R_Axial_DIN0207_L6.3mm_D2.5mm_P10.16mm_Horizontal
26 | R27, R28, R44, R45, R46, R47, R48, R49 | 8 | 1.27k | Resistor_THT:R_Axial_DIN0207_L6.3mm_D2.5mm_P2.54mm_Vertical
27 | R30, R31, R32, R35, R36, R37 | 6 | 1.5M | Resistor_THT:R_Axial_DIN0207_L6.3mm_D2.5mm_P10.16mm_Horizontal
28 | R33, R38 | 2 | 470 | Resistor_THT:R_Axial_DIN0207_L6.3mm_D2.5mm_P10.16mm_Horizontal
29 | R41, R43 | 2 | 150 | Resistor_THT:R_Axial_DIN0207_L6.3mm_D2.5mm_P10.16mm_Horizontal
30 | SW1 | 1 | SW_DPDT_x2 | OSDEHA_AMP:SWITCH_2POLE_ON_ON
31 | U1, U2 | 2 | 6E5P | OSDEHA_AMP:belton_noval-bside
32 | U3, U4 | 2 | 801A | Connector_Molex:Molex_KK-396_A-41791-0004_1x04_P3.96mm_Vertical

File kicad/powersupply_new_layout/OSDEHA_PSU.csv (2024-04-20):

# | Reference | Qty | Value | Footprint | DNP
1 | C1, C2 | 2 | 470u 550 VDC | Capacitor_THT:CP_Radial_D35.0mm_P10.00mm_SnapIn
2 | C3 | 1 | 220u 630 VDC | Capacitor_THT:CP_Radial_D35.0mm_P10.00mm_SnapIn
3 | C4 | 1 | 10000u 25 V | Capacitor_THT:CP_Radial_D25.0mm_P10.00mm_SnapIn
4 | C5, C6, C9, C10 | 4 | 100n 1 kV | Capacitor_THT:C_Rect_L18.0mm_W9.0mm_P15.00mm_FKS3_FKP3
5 | C7, C8 | 2 | 22u 16 V | Capacitor_THT:CP_Radial_D5.0mm_P2.00mm
6 | C11 | 1 | 100n | Capacitor_THT:C_Rect_L26.5mm_W8.5mm_P22.50mm_MKS4
7 | C12, C13, C14 | 3 | 4.7u 630 V | Capacitor_THT:C_Rect_L41.5mm_W20.0mm_P37.50mm_MKS4
8 | CHASSIS1 | 1 | MountingHole_Pad | MountingHole:MountingHole_3.2mm_M3_Pad
9 | D1, D2, D3, D4 | 4 | SBT1845-3G | Package_TO_SOT_THT:TO-220-2_Vertical
10 | D5, D7 | 2 | 1N4007 | Diode_THT:D_DO-41_SOD81_P7.62mm_Horizontal
11 | D6 | 1 | 1N4004 | Diode_THT:D_DO-41_SOD81_P10.16mm_Horizontal
12 | D8, D9 | 2 | 200 V | Diode_THT:D_DO-41_SOD81_P7.62mm_Horizontal
13 | D10 | 1 | 180 V | Diode_THT:D_DO-41_SOD81_P7.62mm_Horizontal
14 | D11 | 1 | GBJ3510 | Diode_THT:Diode_Bridge_32.0x5.6x17.0mm_P10.0mm_P7.5mm
15 | D12, D13, D14, D15, D16, D17, D18, D19, D20, D21, D22, D23 | 12 | STTH512FP | Package_TO_SOT_THT:TO-220-2_Vertical
16 | H1, H2, H3 | 3 | MountingHole | MountingHole:MountingHole_3.2mm_M3
17 | J1, J2 | 2 | 340 VAC / 220 mA | TerminalBlock_Phoenix:TerminalBlock_Phoenix_MKDS-1,5-2-5.08_1x02_P5.08mm_Horizontal
18 | J3 | 1 | 420 VAC / 75 mA | TerminalBlock_Phoenix:TerminalBlock_Phoenix_MKDS-1,5-2-5.08_1x02_P5.08mm_Horizontal
19 | J4 | 1 | 9 VAC / 4.5 A | TerminalBlock_Phoenix:TerminalBlock_Phoenix_MKDS-1,5-2-5.08_1x02_P5.08mm_Horizontal
20 | J5 | 1 | Stator bias | Connector_Molex:Molex_KK-396_A-41791-0002_1x02_P3.96mm_Vertical
21 | J6 | 1 | HV-L | Connector_Molex:Molex_KK-396_A-41791-0004_1x04_P3.96mm_Vertical
22 | J7 | 1 | HV-R | Connector_Molex:Molex_KK-396_A-41791-0004_1x04_P3.96mm_Vertical
23 | J8 | 1 | HEATERS-LEFT | Connector_Molex:Molex_KK-396_A-41791-0002_1x02_P3.96mm_Vertical
24 | J9 | 1 | HEATERS-RIGHT | Connector_Molex:Molex_KK-396_A-41791-0002_1x02_P3.96mm_Vertical
25 | K1 | 1 | RT424006 | Relay_THT:Relay_DPDT_Schrack-RT2-FormC_RM5mm
26 | Q1 | 1 | BD138 | Package_TO_SOT_THT:TO-126-3_Vertical
27 | Q2 | 1 | 10M90S | Package_TO_SOT_THT:TO-220-3_Vertical
28 | Q3, Q4, Q7, Q8, Q11, Q12 | 6 | LND150 | Package_TO_SOT_THT:TO-92
29 | Q5, Q9, Q13 | 3 | NTHL1000N170M1 | Package_TO_SOT_THT:TO-247-3_Vertical
30 | Q6, Q10, Q14 | 3 | BC550 | Package_TO_SOT_THT:TO-92_Inline
31 | R1, R2 | 2 | 787k | Resistor_THT:R_Axial_DIN0207_L6.3mm_D2.5mm_P10.16mm_Horizontal
32 | R3 | 1 | 976k | Resistor_THT:R_Axial_DIN0207_L6.3mm_D2.5mm_P10.16mm_Horizontal
33 | R4 | 1 | 10k | Resistor_THT:R_Axial_DIN0207_L6.3mm_D2.5mm_P2.54mm_Vertical
34 | R5 | 1 | 47k | Resistor_THT:R_Axial_DIN0207_L6.3mm_D2.5mm_P2.54mm_Vertical
35 | R6 | 1 | 787k | Resistor_THT:R_Axial_DIN0207_L6.3mm_D2.5mm_P2.54mm_Vertical
36 | R7 | 1 | 1.91k | Resistor_THT:R_Axial_DIN0207_L6.3mm_D2.5mm_P10.16mm_Horizontal
37 | R8 | 1 | 470 | Resistor_THT:R_Axial_DIN0207_L6.3mm_D2.5mm_P10.16mm_Horizontal
38 | R9 | 1 | 3.3k | Resistor_THT:R_Axial_DIN0207_L6.3mm_D2.5mm_P10.16mm_Horizontal
39 | R10 | 1 | 2k | Resistor_THT:R_Axial_DIN0207_L6.3mm_D2.5mm_P10.16mm_Horizontal
40 | R11 | 1 | 3k | Resistor_THT:R_Axial_DIN0207_L6.3mm_D2.5mm_P2.54mm_Vertical
41 | R12, R13 | 2 | 100k | Resistor_THT:R_Axial_DIN0207_L6.3mm_D2.5mm_P2.54mm_Vertical
42 | R14 | 1 | 4.7M | Resistor_THT:R_Axial_DIN0207_L6.3mm_D2.5mm_P10.16mm_Horizontal
43 | R15 | 1 | 100 5 W | Resistor_THT:R_Axial_DIN0918_L18.0mm_D9.0mm_P22.86mm_Horizontal
44 | R16, R22, R28 | 3 | 1M | Resistor_THT:R_Axial_DIN0207_L6.3mm_D2.5mm_P10.16mm_Horizontal
45 | R17, R19, R23, R25, R29, R31 | 6 | 1k | Resistor_THT:R_Axial_DIN0207_L6.3mm_D2.5mm_P10.16mm_Horizontal
46 | R18, R24, R30 | 3 | 1.5k | Resistor_THT:R_Axial_DIN0207_L6.3mm_D2.5mm_P10.16mm_Horizontal
47 | R20, R26, R32 | 3 | 300 | Resistor_THT:R_Axial_DIN0207_L6.3mm_D2.5mm_P10.16mm_Horizontal
48 | R21, R27, R33 | 3 | 2 | Resistor_THT:R_Axial_DIN0207_L6.3mm_D2.5mm_P10.16mm_Horizontal
49 | RV1 | 1 | 1M | Potentiometer_THT:Potentiometer_Bourns_3296W_Vertical
50 | RV2, RV3, RV4 | 3 | 1k | Potentiometer_THT:Potentiometer_Bourns_3296W_Vertical
51 | U1 | 1 | LM1085-ADJ | Package_TO_SOT_THT:TO-220-3_Vertical
52 | U2 | 1 | NE555P | Package_DIP:DIP-8_W7.62mm

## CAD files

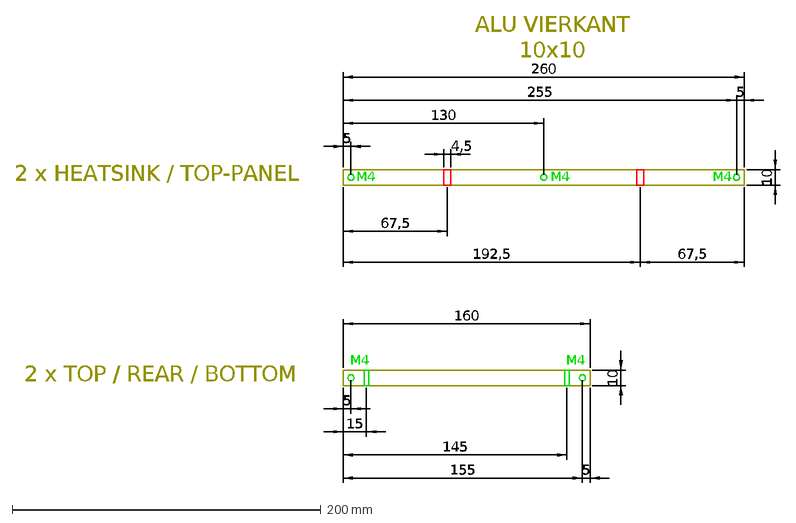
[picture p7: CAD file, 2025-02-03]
chassis/joints.dxf
67,5
192,5
4,5
10
M4
ALU VIERKANT 10x10
160
2 x HEATSINK / TOP-PANEL
2 x TOP / REAR / BOTTOM
5
15
145
155
260
255
130

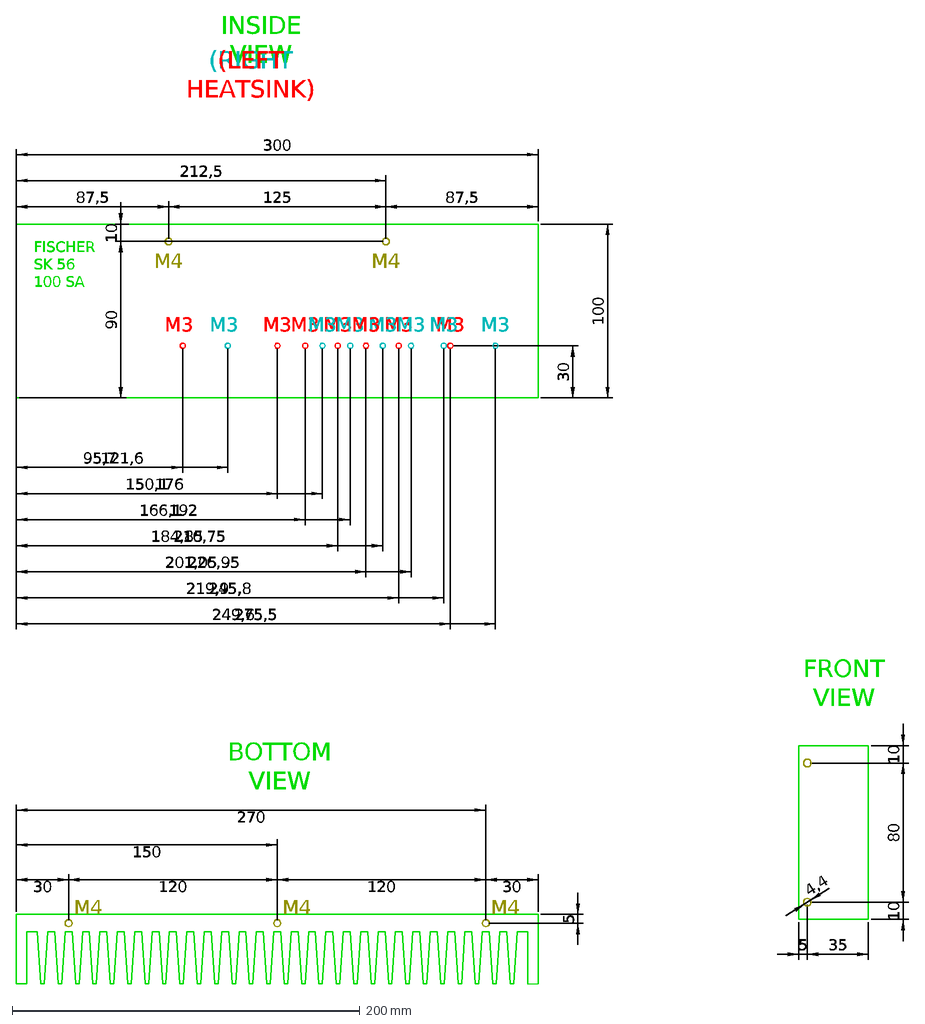
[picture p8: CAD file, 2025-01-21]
chassis/heatsink_drillplan.dxf
100
87,5
10
80
5
35
FRONT VIEW
4,4
M4
166,1
249,6
M3
30
FISCHER SK 56 100 SA
275,5
90
212,5
INSIDE VIEW
300
125
245,8
226,95
210,75
176
121,6
192
(RIGHT HEATSINK)
(LEFT HEATSINK)
219,9
184,85
150,1
201,05
95,7
120
150
270
BOTTOM VIEW

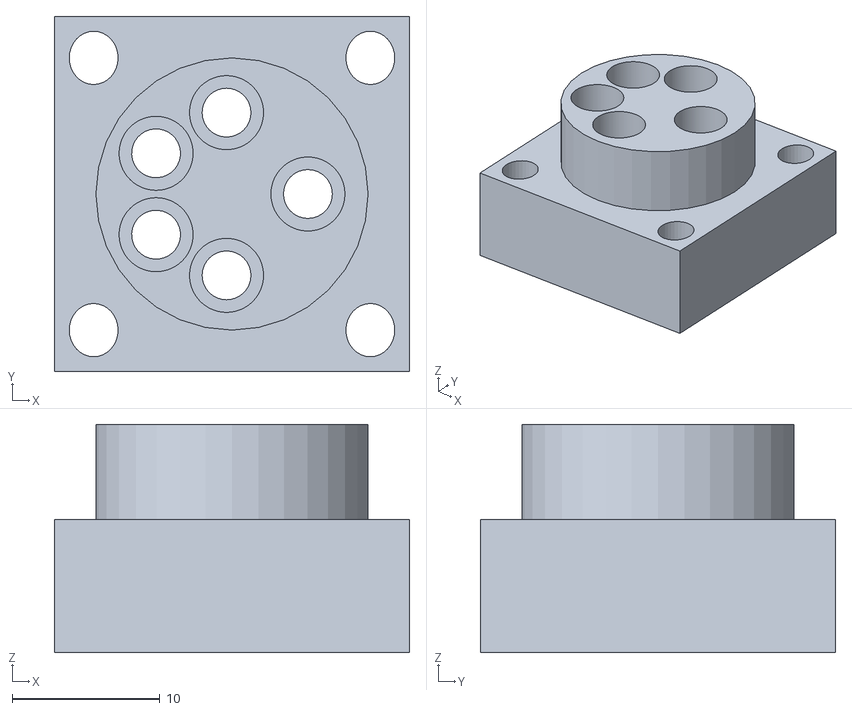
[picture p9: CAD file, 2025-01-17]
chassis/Stax_female_socket_chinsettawong_diyAudio.stl
24.0 x 24.0 x 15.4

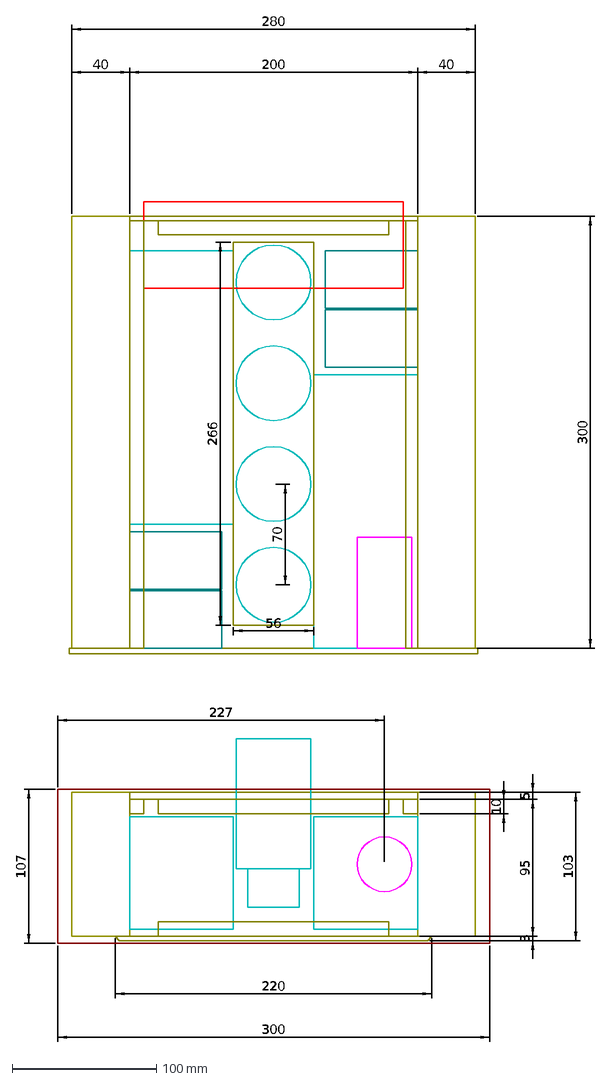
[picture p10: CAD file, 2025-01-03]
chassis/amp_chassis_layout.dxf
200
280
300
40
220
95
5
103
10
107
3
227
56
266
70

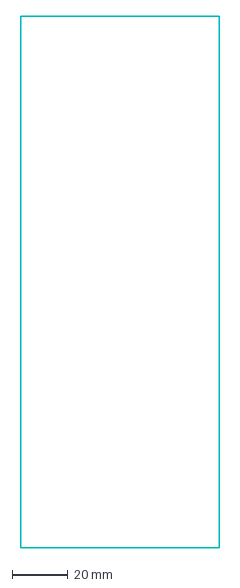
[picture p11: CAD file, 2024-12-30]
chassis/parts_arrangement.dxf
71.5 x 191.2 mm

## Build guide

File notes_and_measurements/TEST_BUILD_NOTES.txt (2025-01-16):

Build and test log

2024-04-20
- Built and tested heater supply for input stage tubes + relay for HV delay. Needed to reverse one of the rectifier diodes. Seems to work ok, but still need to test htr supply with proper load.
- Built negative bias + buffer HV supply. Needed to attach part of the GND plane to GND (was not connected on PCB).

2024-04-21
- Tested neg. bias + buffer HV supply. Needed to adjust some of the resistor values in the CCS for voltage reference. Works ok, also under load of up to 120 mA.
- Built B+ and B- supplies. Did not yet test them.

2024-05-03
- Tested delay switch for B+ and B- supply. Works.
- Tested B+ and B- supply (without load). Works. Adjusted to +/-440 VDC out.

2024-05-04
- Tested PSU board using the Toroidy mains transformers (instead of DC input from bench PSU as before). Works.
- Built HV BIAS supply. Tested by loading it with a 4.7 uF capacitor for a few seconds, then meansured the voltage across the cap using a DVM. Voltage drops due to internal resistance of DVM, but first reading was above 500 VDC, so it seems to work ok. (see also further measurement 2024-05-09)

2024-05-04
- Moved PSU board to prototype chassis with IEC inlet and mains switch for easier and safer work
- Tested ground loop breaker. Works as expected.

2024-05-09
- Installed mains transformers and wiring in proto chassis
- Tested PSU in proto chassis (ok)
- Measured diaphgragm BIAS using a very high value resistor (approx 10 G Ohm) in series with the DVM (internal resistance approx. 10 M Ohm). The 10 GOhm resistor effectively reduces the load on the BIAS supply. Calibrated the DVM readings from other PSU outputs. Result: BIAS = 575 VDC (that's less than 1% off from the target!). Perfect.

2024-05-11
- Built amplifier input stage. Picked random 6E5P tubes from the box (no matching etc.):
	Operating points around tubes are as expected (measured: 11 mA Ic, 3.1 V-cathode, Va = 152 V and 142 V)
	Measured gain = 30.1 dB = 32x
	Captured harmonic and IM distortion spectra at output voltages of 1.0, 3.16, 10, and 31.6 Vrms. Looks ok.
- Replaced 6E5P tubes with a nicely matched pair to check for improvements in circuit balance and distortion spectra
	Operating points are very symmetric (Va = 153 V and 154 V), distortion spectra are cleaner (sometimes a by a lot)
- Comparison of harmonic distortion with unmatched / matched 6E5P input tubes:
	V-out (Vrms)	matched		2nd (dB)	3rd (dB)
	1.0		no		-92		--
	1.0		yes		--		--
	3.16		no		-85		-91
	3.16		yes		-91		-110
	10		no		-76		-86
	10		yes		-83		-91
	31.6		no		-64		-94
	31.6		yes		-79		-91

	--> 2nd is always considerably lower with matched tubes, 3rd is sometimes lower.
- Probe slip --> short and bang! Let's stop for today...

2024-05-12
- Built and tested 4 x Coleman DHT Filament Regulators.

2024-05-13
- Work on circuit+PCB design for HV PSU protection (following Jan Didden T-Reg description). Increased trimmer R value for HV time-delay switch to allow longer turn-on delay.
- Work on PCB design for raw-DC supply for Coleman DHT Filament regs.
- Found issue with HV PSU after short (test probe slip): protection Zeners on MOSFets (G-S) shorted out. One MOSFet was drawing a lot of grid current, which messed up the CCS voltage reference. Replaced all HV MOSFets and Zeners.

2024-05-14
- Tested HV PSU: output voltages are ok again, adjusted to target values. Measued voltage drop across the MOSFet gate resistors (300 Ohm): one had 0.0 mV, the other two had 2.7 mV --> gate current is < 1E-5 A, or 50x less than CCS current.
- Check parts on amp board (IPS) after short (probe slip and bang) on 2024-05-11. Replaced the DN2540 parts in the CCS (just in case they were damaged). All resistors checked ok. 6E5P heaters are ok, but the anode/cathode/grid system is shot. Replaced the tubes. Amp IPS now works again. Test signals taken after DC-coupling caps (470nF):
	- Output (balanced) sine signal starts clipping at 106 Vrms. Thats 300 Vpp.
	- Triangle and rect signals are clean, no overshoot.
	- Frequency response is flat up to 720 kHz, where sine signal is down by 1/2x (-6 dB).
	
2024-05-15
- More work on PCB layout for HV PSU (avoid vertical small resistors for easier debugging)
- Fixed errors on amp schematic and PCB (wrong CCS connection, wrong pinout on some FETs). Further improvements on PCB layout.
- Tested fixed-bias voltage adjust/range. Works ok.
- Tested buffer stage. Does not work, seems to short out the HV B2- supply somehow. I can't figure it out, possibly due to the messed up pinout and CCS connection (I tried some workarounds on the PCB, but no success). Tested CCS and buffer circuit in a dead-bug build, and that seemed to work as expected.
- Finalized new version of PCBs (amp, HV PSU, DC-raw filament PSU), exported Gerbers, and ordered new PCBs (JLCPCB).

2024-05-16
- Built wire harness with load resistors for HV PSU for easy and simultaneous testing of the PSU under load: 4-pin KK396 on PSU/PCB end, other end of wires to 3 x 27k power resistors linked to GND.
- Tested PSU again using the load harness: B+ and B- were fine, B2- was at -50 VDC instead of -550 VDC. Removed NPN-BJT (BC550) from current limiter, which fixed the issue (B2 = -549 VDC under load). NPN-BJT was confirmed broken with component tester. Looks like I destroyed the BC550 during some mishap, but did not notice it because the B2- PSU showed the correct voltage (when it was not connected to a load!), so I missed this.
- No-functional buffer stage in the amp (see 2024-05-15) was most likely related to the misbehaving B2- supply.

2024-05-25
- Rebuilt amp (IPS and buffer) using new PCBs. Works as expected. Buffer output starts clipping at 144 Vpp, which is way more than needed to drive the the output stage to full output. No ringing or oscillations visible on scope with triangle or square wave signals. Bandwidth is 670 kHz (-3 dB) or 1 MHz (-6 dB).

2024-05-26
- Determined values of R15 (R20) to get Vbias adjustment centered at target value at output of buffer stage --> R15 = 18.7k is a good value (with R12=47k, R14=20k and R11=1M) --> Vbias = -478V at buffer output if R14/pot is at center position.
- Gate current for Q3 (Q4): voltage across R13 (1M) is <0.2 V, so current is less than 0.2 uA.
- Built and tested raw DC supplies for Coleman Regs. Tested (without load), looks ok.

2024-06-01
- Wired DHT output tubes and Coleman Regs to amplifier board. Tested and adjusted filament supply through amplifier board, works ok.
- Built output stage on amplifier board (mu follower etc.). Connected HV PSUs (B+, B-, B2-). Does not work. Smoke from AOT Fets (or something nearby, could not see well).

2024-06-02
- Rebuilt mu follower / CCS with correct pinout on the FETs. No more smoke, but still does not work. Does the tube/anode load down the protection Zeners and then pulls the gate and the 4.5M resistor low? There is quite a bit of DC across the 4.5M resistor. Also, the B+ supply was broken, so that may also have caused problems with the mu follower / CCS.
- Rebuilt PSU using the new PCB. 6.3 V heater supply tested ok. Need to test the remaining parts.
- B2- supply of new PSU-PCB does not work (B+ and B- not yet tested). Testing B2- without Q5 installed. Very low voltage across RSET. Voltage across R18 (1k) is 0.5V, so CCS current is 0.5 mA (about right). Does the overcurrent limiter (Q6) suck up all the current coming out of R18? --> remove Q6 and check again.

2024-06-03
- Pinout of 2N3904 Q6/Q10/Q14 is backwards on amplifier PCB. This would explain why the current is "sucked out" of the CCS, upseting the voltage reference in the HV PSU.
- Fixed pinout on PCB design.

2024-06-07
- Repaired B2- HV PSU and built B+ and B- HV PSU (using correct pinout of 2N3904 BJT). Tested ok.
- Tested amplifier mu follower / CCS --> killed B+ HV supply again (cf. 2024-06-02).
- Repaired B+ HV supply, using STF5NK100Z (TO220FP) instead of NTHL1000N170M1.
- Tested amplifier mu fullower / CCS again (without DHT tube installed) --> one branch works ok (Anode out at 4 VDC, close to GND), the other has B+ / 440 VDC at Anode out.
- Replaced AOT1N60 and IXTP3N100D2 --> both branches now work ok (ca. 4 VDC at Anode out)

2024-06-08
- testing amplifier / mu follower CCS stage: found poor insulation between HV MOSFETs and heatsink, which caused shorts. Also found poor solder joint on gate resistors of AOT160. Fixed.
- Testing amplifier / mu follower CCS using bench PSU for better control of current limits, starting at lower voltages. DC operating points work ok with 20k load resistors inplace of DHT tubes.
- Testing amplifier / mu follower CCS using OSDEHA HV PSU, with 20k load resistors in place of DHT tubes. DC operating points work ok.
- Testing complete amplifier (input, driver, output mu follower CCS + DHTs) --> DC operating points in output stage ok. Can adjust DC bias to target 20 mA idle current, but DC bias is not perfectly stable but has regular pulses (approx 1 pulse per second). The fluctuations stop if the DHT tubes are disconnected.

2024-06-10
- Pulsating voltage in mu follower CCS stage (and elsewhere) only happens with DHT tubes installed. If dummy resistors are used instead, pulsation is gone.
- Pulses are from RFI/EMI noise pickup. Not specific to OSDEHA! Scope also shows similar pulse signals if probing the solder tin spool.

2024-06-11
- Design note, HV PSU (B+, B-, B2-): replace BJT current limiter with a 10M90S current limiter for use during testing. Once testing is completed, the 10M90S can be replaced by a jumper to avoid any effects of the current limiter on the HV (output impedance, etc.)
- Design note, Mu stage / DHT load: optimize the Mu resistor to prevent it from burning out: can use a slightly lower R value for less dissipation? Use a part with higher dissipation spec? --> use CPF3470R00
- Design note, Mu stage / DHT: insert a proper gate stopper resistor to the CCS FET (like 100-300 Ohm) --> not needed, as gate is already stoppered by the resistor(s) to GND.
- Adjusted output stage to 20 mA idle at each DHT
- Testing amp:
	output clipping visible on scope at 1550 Vpp (using 1:100 resistor voltage divider 100k + 2k + 100k at output and differential scope probe)
	voltage gain output/input = 241x
	frequency response into 200k resistive load (-3 dB) = 10 Hz ... 500 kHz
- Testing amp at high power output, the mu follower CCS cascode FETs Q6/Q8 tend to die. Too much heat? Or too much voltage? Or oscillation?
	- Added thermal paste to one cascode FET (but not the other) --> the one with paste dies again, while the other survives. Not a heat problem.
	- Reduced B+, B-1 and B2- voltages to +400...-500V, so there can't be more than 900V across the cascode FETs, which are specified to 1000V --> they still die. --> Not too much voltage.
	- Cascode FETs don't die while idling, they mostly die when the amp is driven hard with high frequency test signals. Oscillation? Try with larger gate resistors (both at cascode and main CCS FETs).
	(See also https://www.bartola.co.uk/valves/2019/02/03/hybrid-mu-follower-aka-gyrator-rev08-pcb-update --> use of dedicated gate stopper 330R for CCS FET is needed to prevent oscillation!)
	
2024-06-13
- Inserted 330R gate stoppers to CCS FETs, testing the output stage again:
	- DC operation is fine, same as before
	- AC operation with tubes shows less runaway, FETs do not blow up.
	- Driving the output stage hard with high-frequency test signal causes a "flame" in one of the DHT tube. Immediately turned the amp off. Testing output stage with DC bench supplies and dummy load resistors, and it seems fine.
	- One of the CCS loads on the buffer stage burned out. Oscillation? Rebuild CCS, but with larger gate stopper?

2024-06-14
- Repaired buffer stage / CCS. Confirmed working ok using bench PSUs.
- Changed gate stoppers at DN2540 and IXTP parts from 300R to 1k
- Found 100R gate stoppers at DHT tube sockets were toasted. Replaced with 220R.
- Added grid voltage clamp diodes to DHT tube sockets.
- Testing amp with new gate stoppers and diode clamps at DHT grids, but without tubes. Works ok, clamp works.
- Testing amp with one DTH and one dummy load resistor. Tube shows osciallation at 2 MHz, but no runaway. Dummy resistor is clean.

2024-06-16
- Checking for source and cure for oscillation.
- Removing diode clamps at tube sockets does not change oscillation.
- Adding RC snubber (R=10k, C=100p Mica) from anode to cathode/filament on tube socket has only very little effect to reduce the oscillation.
- Oscillation looks like a smoothe sine wave at the tube pins, but less smooth saw-tooth at the PCB pins. This means the HF stuff happens on the PCB side, not at the tube side of the connection leads between PCB and tube.
- Reducing mu resistor in mu stage from 450R to 300R changes oscillation from continuous to intermittent. Reducing it further to 150R, and oscillation is gone. Looks like there was too much feedback in the mu-stage CCS.
- Can the clamp diodes, RC snubber and gate stopper resistor at the tube socket be reduced again? (or entirely removed?)
	- re-installed clamp diodes --> no oscillation
	- remove RC snubber --> no oscillation
	- remove grid stopper --> no oscillation
- Further testing to check how output stage behaves if driven hard --> input/buffer stage blows up. Buffer CCS FETs broken. Repaired. Input stage does not work, no current through tubes. Checked resistors and replaced FETs in tail CCS, still does not work. Tubes ok?

2024-06-22
- Repaired input + driver stage
- Installed DN2540 instead of AOT1N60 as CCS "lower" FET in mu-stage. DC operating point comes out as expected.

2024-06-23
Checking input + driver stage after repair.
- Tried backwards diode from Drain-to-Source on CCS FETs to protect from negative voltage spikes. No effect. The CCS behaves ok even if the CCS FET Drain is driven negative. The FET just shorts the negative spike to B2-, so the diode is useless (confirmed with scope). Removed the diode from the schematic and PCB.
- Found buffer CCS to run at 40 mA bias instead of 10 mA. This may explain the death of the buffer CCS FETs (overheating if driven hard). Increased R-sense values to give 10 mA on board. Changed CCS sense resistors from 150R to 536R in schematic.
- With bench supplies (B+ = 200 V, B- = -60 V, B2- = -160 V): Driver/buffer does not blow up when driven hard into no load, dummy load (resistor + cap), 

2024-07-05
- Testing amp with bench PSUs and a single KT66 dummy (other branch has dummy resistors):
	- Works fine in general
	- There's some noise on the scope traces. Where's that from? Ground loop somehow?
	- Driver/buffer does not blow up when driven hard (300 kHz signals deep into clipping)
	- Increased Rmu to 470 Ohm again, seems to work fine with DN2540 (instead of AOT1N60)
	
2024-10-19
- PSU: tested TO220 BJTs for overload protection. Progress, protection now work ok. Except: Series FETs still die before BJT protection kicks in if there's an instantaneous short.
- Removed tweaks needed for previous tests with KT66 tubes. Brought amplifier up, step by step (front end only, then with VT25 test tubes). Works!
- Warming up with no signal, monitoring DC bias current via voltage across mu resistors. Adjusted a few times to 20 mA (9.4 V across 470R mu resistors) until it was stable after a couple of minutes.
- Testing AC output (using diff probe across balanced output):
	frequency response with MU/CCS switch = mu-stage mode (no load except diff probe):
	lower end: 7 Hz -3 dB-rel, 5 Hz -6 dB-rel.
	upper end: 180 kHz -3 dB-rel,  340 kHz / -6 dB-rel.
- Driving amplifier hard with triangle signal to clipping at approx. 1.6 kVpp. Does not blow up or do other funny things.

2024-10-20
- Testing AC output frequency response with 100 pF dummy load (using diff probe across balanced output):

	MU/CCS switch = mu-stage mode:
	lower end: 8.8 Hz -3 dB-rel, 5.5 Hz -6 dB-rel.
	upper end: 77 kHz -3 dB-rel,  123 kHz / -6 dB-rel.

	MU/CCS switch = CCS-mode:
	lower end: 8.7 Hz -3 dB-rel, 5.5 Hz -6 dB-rel.
	upper end: 50 kHz -3 dB-rel,  87 kHz / -6 dB-rel.
	
- Not running the amplifier to full amplitude output because dummy capacitor is rated to 500 V only

- PSU testing at 220 VAC mains (instead of 230 VAC) to determine headroom of stabilizers vs. max. DC output voltage:

	with no load, raw DC after rectifiers:
	- B+ and B-: raw DC = 447 VDC @ 220 VAC mains (raw DC = 466 VDC @ 230 VAC mains)
	- B2-: raw DC = 
	
	with 27 kOhm dummy load on each B+, B- and B2-:
	- B+ and B-: raw DC = 432 VDC @ 220 VAC mains (raw DC = 452 VDC @ 230 VAC mains)
	- max B+ and B- at 220 VAC mains before stabilisation cuts off = ca. 422 VDC at PSU output (current = U/R = 15.6 mA)
	- max B2- at 220 VAC mains before stabilisation cuts off = 525 VDC at PSU output (current = 19.4 mA)
	
	with real load of two STEREO amps = 60 + 60 mA (B+, B-) and 20 + 20 mA (B2-), the cut off will tend to happen at slightly lower voltages.
	--> estimated target values (will need confirmation later with real amps in place):
	B+ and B- = +/- 420 VDC
	B2- = 520 VDC
	
	--> adjusted HV PSU output to these values --- NEED TO CONFIRM ONCE BOTH AMPLIFIER BOARDS ARE HOOKED UP TO THE HV PSU!!!

2024-12-30
- CCS LTP current:
  target value is 20 mA
  measured with R6=75 Ohm: V-drop = 1.665 V --> current = 22.2 mA, about 10% high, not bad
  --> possibly use slighly higher R6 value of avout 82 Ohm (CMF5582R000)

- CCS buffers/drivers:
  target value is 10 mA
  measured with R42 = 494 Ohm: V-drop = 5.75 V --> current = 11.6 mA
  measured with R44 = 470 Ohm: V-drop = 5.45 V --> current = 11.6 mA
  --> different R values on different FETs give some current, showing the part/parameter variation
  --> possibly use slightly higher R42/R44 value of about 540 Ohm (CMF55536R00)
  
- HV PSU sags under load. Too much ripple / not enough headroom/dropout?
  Dialing it further down to:
  B+/B- = +/- 400 VDC
  B2- = -500 VDC
  --> this is stable enough with load = dummy resistors + 1 amp channel
      use this setting for testing, but will need to revise PSU / transformer later (see next item)
  
- Revise specs of HV transformer secondaries:
	
	Current transformer has:
	Secondaries 1 and 2: 325 VAC / 220 mA
	Secondary-3: 415 VAC / 75 mA
	
	* We need at least 20 V more
	* We don't need this much current:
		- B+ and B-: 60 mA per channel, so 120 mA total
		- B2-: 20 mA per channel, so 40 mA total
	* We can't exceed the voltage limits of the PSU caps if/when the PSU runs without any load:
		- max. 550 VDC for B+ and B- --> max. AC = 550 / 1.414 = 389 VAC, even with 10% high mains, so max. secondary AC is 370 VAC
		- 630 VDC for B2- --> max. AC = 550 / 1.414 = 446 VAC, even with 5% high mains, so max. secondary AC is 424 VAC
	* For transformer current rating, see:
	  https://www.sowter.co.uk/rectifier-transformer-calculation.php
	  min. AC current rating of transformer = 1.61 x DC output current
	* Note: Toroidy does not (like to) make transformers with summed voltages of all secondaries higher than 1000 VAC. Maybe look at other manufacturers if necessary.
	
  ====> **** New specs for transformer secondaries ****
	Secondaries 1 and 2: 350 VAC / 200 mA
	Secondaries 3: 420 VAC / 70 mA

*** TO DO ***
  
- Adjust revision number/date on next version of Gerbers

- check HV PSU dropout / ripple again! Can't get stable output under load higher than +/-400 VDC
	--> found AC from transformer secondaries to be lower than speced:
	- design target B+/B- AC secondary = 340 VAC
	- true AC secondary = 330 VAC
	- B2- design target = 420 VAC / true AC secondary = 400 VAC
	- Playing with Variac shows that design target should be increased to 345..350 VAC or so for a bit more headroom, allowing proper +/- 420 VDC output
	--> revise specs for HV mains transfomer:
	B+ and B-: 350 VAC / 220 mA
	B2-: 430 VAC / 75 mA

- (re-)Build 580 V bias supply and test amp with headphones hooked up VIA SAFETY RESISTORS!

- Rebuild 2 x amp and PSU, install in (temporary/mockup) chassis.

- Confirm/test/validate HV PSU stabilizers once real STEREO amp with full current draw is in place: make sure HV ouput can be adjusted to correct target values with mains variable from 220...240 VAC, no cut-off due to ripple on raw DC and drop-out limit on voltage reference (see also 2024-10-20 tests):
	B+ = 420 VDC
	B- = -420 VDC
	B2- = -520 VDC
	
- Design chassis, determine mechanical arrangement and construction. See ../chassis/chassis_notes.txt

*** COMPLETED TO-DO ITEMS ***

- DONE Put back labels of output/input connectors on AMP board!
  (Also check PSU board!)

- DONE Adjust values of CCS sense resistors R6, R42 and R44 (see 2024-12-30)

- DONE Check LTP CCS: current at target value 20 mA?

- DONE Check buffer CCS loads: current at target value 10 mA? Voltage drop across R42 and R44 (536 Ohm?). Adjust CCS sense resistor if necessary.

- DONE Repeat 2024-10-19 tests with realisic dummy load (100 pF capacitor through 5.1k "safety" resistors)

- DONE Check buffer CCS loads: current at target value 10 mA? Voltage drop across R42 and R44 (536 Ohm?). Adjust CCS sense resistor if necessary.

- DONE PCB layout: add test point for such that it's easy to attach probes/clips for monitoring and adjusting DC bias. Example: Keystone 5010 test point

- DONE (for now): Powersupply: try the beefy high-voltage BJTs for the overload protection. --> test with controlled load somehow.

- NO, THAT'S NO GOOD (WOULD CAUS TOO MUCH RIPPLE UPSTREAM THE VOLTAGE STABILIZER, CAUSING THE CCS TO CUT OFF!) Powersupply: Save space by using smaller caps after rectifier in B+ and B- PSU (similar to those in B2-)?
  --> will need to look at ripple on rail voltage once amp is up and running.

- DONE If HV PSU works fine with the beefy high-voltage BJT current limiters
	--> repeat amp testing with the proper PSU in place (instead of bench PSUs)
	--> repeat amp testing with VT25 DHTs instead of KT66 (adjust grid bias voltage!!!)

- DONE, BUT ONLY TESTED AT DC SO FAR: FOR TESTING IN ONE BRANCH: Change AOT1N60 to DN2540, which has much lower saturation voltage and will therefore provide stiffer CCS at the 4...5 V drain-source voltage provided by the Vgs value of the IXTP cascode FET. Capacitances and gfs are very similar between the AOT1N60 to DN2540 parts. That might also help with the oscillation issue in the mu-stage, allowing a larger Rmu resistor for higher CCS impedance.

- DONE, BUT MORE TESTING MAY BE USEFUL (ISSUE WAS LIKELY THE EXCESSIVE CURRENT IN THE CCS OF THE BUFFER STAGE): Figure out what causes the failure of the driver/input stage when driving the tubes hard:
	- (so far, the failure only happened when the DHT grids were connected to the buffer stage)
	- overvoltage across CCS FET? DN2540 is good to 400V across Drain-Source, but there might be more during large signal swings. Replace with IXTP3N100D2 (use approx. 330 Ohm sense resistor for 10mA).
	- DIODE CAN'T LIMIT THE HF SPIKES IN CCS, NO CHANGE ON SCOPE! add protection diode in buffer CCS to prevent CCS FET drain from swinging below source voltage, which is linked to B2-
	- Test 1: drive it hard without tubes (high frequency, high amplitude)
	- Test 2: somehow simulate grid load without DHT tubes to better understand what's going on
	- Test 3: use an old dummy tube (instead of the valuable VT25 / 801A DHTs) to test the amp. An KT66 should do, may need somewhat more negative grid bias.
	
- DONE (WITH KT66 DUMMY): Rmu = 470 Ohm works fine with DN2540.
Determine the max. Rmu in the output mu-stage that does not lead to oscillation (with DN2540)? --> order parts with suitable power spec.

- Check: what happens if the output voltage from the input/driver stage swings close (or even beyond) B2-. What happens in the CCS loads of the buffer stage if this happens? Should there be a protection diode from Drain to Source of the CCS FET to prevent the drain from swinging negative relative to the Source?

- CHECK: are there fusible resistors that would work for the 5.1k current limiter / safety resistors at the headphone outputs?

- PCBs: redo the part labels/numbers for more consistent numbering.

- (DONE??? CHECK...) Change R13 and R18 to lower value (100k) for tighter bias control and fc = 3 Hz
- Change R30+R31+R32 and R35+R36+R37 from single 866k to 3x series parts (to keep them within the power/voltage limits)
- B+ and B- HV PSU: Change RSET value from 866k to 890k or 900k or so. <-- really necessary???
- (Really? Naahhh...) HV PSU: replace NTHL1000N170M1 with STW5NK100Z (TO247)
- DONE / DACT 10k -- choose/decide on volume pot: need 4-deck attenuator with very tight matching to maintain the symmetry of the balanced input --> switched attenuator using fixed low-tolerance resistors is a good idea.
- design chassis, mechanical construction
- for later: design integrated DHT filament supply containing rectifiers, Raw DC filtering  and FILAMENT CCS

PCB / design notes
To-Do list for the kicad projects:

General:
- Try to use same make/type of parts and footprints where suitable to make life easier with ordering parts and fitting them on the PCB.
- Check correct pinout, especially with FETs and stuff. And double check! (Derived footprints may have different pinouts...)
- Check for correct footprints. And double check.
- Check for consistency of board connectors:
	* same type of connectors on both ends
	* consistency of pinout on both PCBs
- Dimensions of boards should fit the chassis, and the different boards should fit next to each other and around the power tubes, mains transformers, volume control, etc.

Connectors, sockets
- Use Molex KK or MiniFit Jr (gold contacts would be nice, check voltage limits and other specs)
- Molex MiniFit Jr:
	https://www.mouser.ch/new/molex/molex-minifit-jr-connectors
	Max voltage: 600 V
	Max current: 13 A
	no gold contacts available (?)
- Molex KK:
	https://www.mouser.ch/new/molex/molex-kk
	Series KK-396 max voltage/current: 600 V / 5 A
	Series KK-254 max voltage: 250 V

Grounding:
- Connect circuit GND to Chassis/PE via ground-loop breaker on the PSU board.
- Connection from PCB to chassis: separate wire, or via metal screw mount connecting to PCB?

FETs:
- Check for need of Zener protection diode(s). Some types have built-in Zeners, others dont.

Amplifier board:
- There will be two boards for Left and Right channels mounted to the heatsinks on the sides of the chassis.
The boards will be rotated by 180 degrees. Connectors should therefore be on the PCB side on the far side from the heatsink, towards the inside of the chassis (not on the front/rear sides).

Coleman DHT regulators:
- Can the Coleman boards sit on the main amp boards piggy-back style?

Boards overview / notes
OSDEHA PCBs / boards

A complete set of PCBs for a stereo OSDEHA consists of the following:

2 x amplifier boards
1 x power supply board (HV supply, heater supply for input tubes, stator BIAS, HV power-on delay)
4 x Coleman DHT Filament regulators (PCBs + parts kit from Rode Coleman)
2 x Raw DC supply for Coleman DTH Filament regs
1 x volume control board (different versions for different pots: Alps RK27, Khozmo, etc.)

Mains transformers:
1 x mains transformer for HV supply (B+, B-, neg. HV for buffer + grid bias)
1 x mains transformer for filament / heaters supply_
	- 1 winding for heaters of input tubes (regulated DC, common for both channels)
	- 2 windings for raw DC supply to Coleman DHT filament regs (each channel has 1 x raw DC supply for 2 x Coleman regs)	
	
1 x Mains transformer for HV supply
toroidal, “Audio” grade with shields beween windings
Primariy: 2 x 115 VAC
[secondary specs see test notes and Kicad schematic!]

1 x Mains transformer for heaters and DHT filaments
toroidal, “Audio” grade with shields beween windings
Primariy: 2 x 115 VAC
[secondary specs see test notes and Kicad schematic!]

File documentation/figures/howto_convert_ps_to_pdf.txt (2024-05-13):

Example:
ps2pdf -dEPSCrop OPS_concept.ps OPS_concept.pdf

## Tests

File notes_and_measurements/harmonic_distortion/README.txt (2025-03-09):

Harmonic distortion tests
mbrennwa, 9 MAR 2025
harmonic spectra from 1 kHz fundamental at different levels (up to the limit of the RTX audio analyser of 100 Vrms)
Using REW and RTX analyzer
MU-OUT and ANODE-OUT

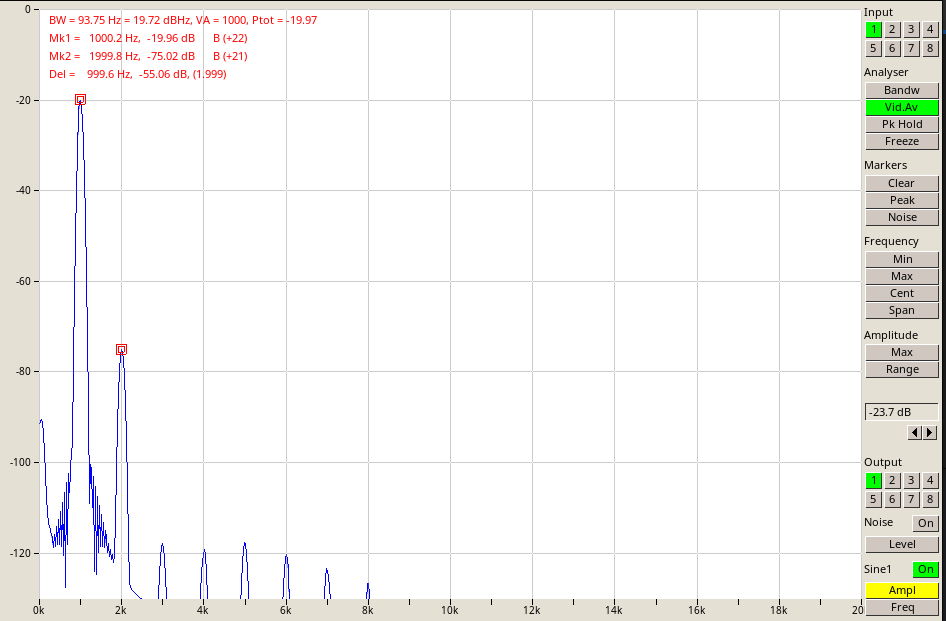
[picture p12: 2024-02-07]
notes_and_measurements/input_tubes/6E5P_Ia20mA_Vg3V_Rk14k.png

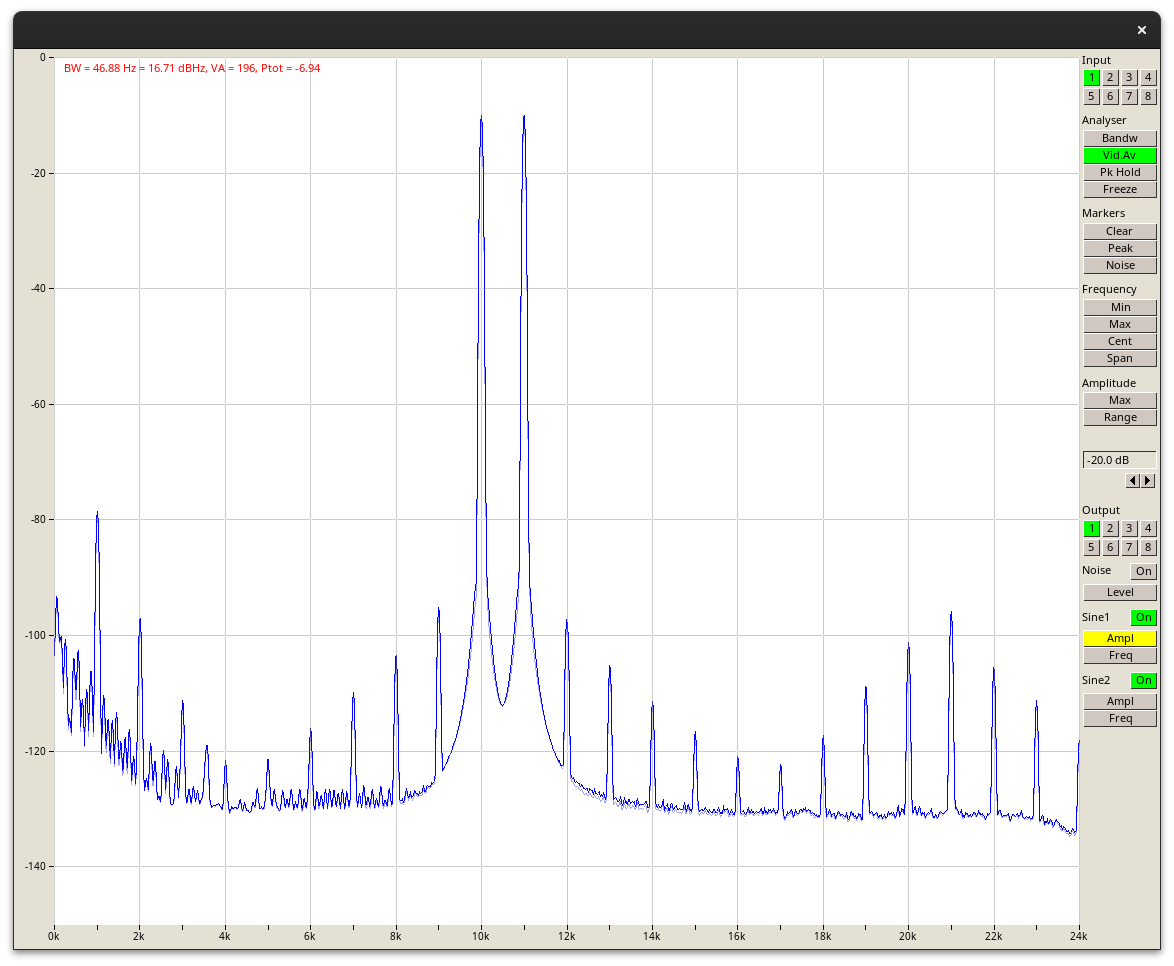
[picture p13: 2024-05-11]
notes_and_measurements/2024-05-11/IPS_6E5P_No.29.34.matched/OSDEHA_IM_VOUT3.16.png

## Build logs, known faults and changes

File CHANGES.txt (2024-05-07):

This file is meant to list any changes made to the original OSDEHA project.

Anyone modifying the design should provide brief information about the modifications, including the date they were made. Information about the design should be added but never removed from that file.

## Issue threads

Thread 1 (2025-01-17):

Rear panel has inconsistent screw holes for socket mounts

mbrennwa, 2025-01-17:
PSU connectors have holes for countersunk heads, while audio XLR connectors have flat-head holdes.

Closed 2025-01-17.

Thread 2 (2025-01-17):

Chassis bottom plates are missing a screw hole for Earth connection

mbrennwa, 2025-01-17:
Need a hole for an M5 screw to provide a dedicated earth connection.

mbrennwa, 2025-01-19:
Need dedicated earth/PE screw-connection on both chassis (PSU and AMP)

Closed 2025-01-30.

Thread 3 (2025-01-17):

Correct CAD drawing for transistor mount holes on heatsinks (left/right heatsinks are different!)

mbrennwa, 2025-01-17:
The current drawing is correct for the left heatsink, but not for the right one. Expand the drawing to include the positions of the M3 transistor mount holes on the right heatsink.

Closed 2025-01-18.

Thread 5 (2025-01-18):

Lower subchassis mount?

mbrennwa, 2025-01-18:
How much space is needed between the bottom plate and the subchassis for DHT tubes? There should be a good air gap between the bottom plate and the pins of the tube sockets / filament test points.
--> adjust spacer length accordingly (also in the partslist)

mbrennwa, 2025-01-19:
With tube sockets mounted to the underside of the subchassis panel, standoffs need to be 30 mm long.

Closed 2025-01-19.

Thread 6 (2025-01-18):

Amplifier build

mbrennwa, 2025-01-18:
- [ ] Confirm positions for M3 transistor mount holes on right heatsink
- [ ] Drill/tap M3 transistor holes on right heatsink
- [ ] Complete amplifier board, install in chassis
- [ ] Build amp rear plate
- [ ] Build umbilical cables for connection to prototype PSU
- [ ] Bring up new amplifier (following steps in documentation file, adjust doc if/where necessary)

mbrennwa, 2025-02-01:
Figure out issue with Coleman Reg: one board has 0 V output!?

mbrennwa, 2025-02-01:
Figure out low bias of buffer stages [is 5mA, should ve 10mA]

mbrennwa, 2025-02-02:
Prototype amplifier works with music playback!
- Mono only so far
- Bias voltage "stolen" from another estat amp (bias supply is missing in current PSU build)

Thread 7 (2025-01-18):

Confirm dimensions of chassis cutout for IEC mains inlet

mbrennwa, 2025-01-18:
Template used was for Schurter KM type with extra shielding. However, the shielding is not necessary, so the dimensions can be changed to fit a Schurter KM without shielding (will use KM00.1105.11). Dimensions are here: https://www.schurter.com/de/datasheet/typ_KM.pdf

- Datasheet dimensions: 46.8 x 27.8 mm
- Measured dimensions for part without shielding: 47 x 28 mm

--> use 47.5 x 28.5 mm cutout

Closed 2025-03-15.

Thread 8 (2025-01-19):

Redesign mounting of amplifier front plate

mbrennwa, 2025-01-19:
Current design with blind holes and headless screws into front fins of heatsink is finicky.
Use mountpoints inside the chassis? (2 on inside of heatsinks, near the top and one at the bottom in the center of the bottom panel?)

mbrennwa, 2025-01-22:
This may be useful to hold the front panel to the heatsinks and bottom plate (and top, too?):
https://www.buerklin.com/de/c/elektromechanik/befestigungsmaterial/montagewinkel-montagebloecke/30201300/

mbrennwa, 2025-01-22:
Additional L brackets:

https://www.buerklin.com/de/c/elektromechanik/befestigungsmaterial/montagewinkel-montagebloecke/30201300/

https://shop.lasatec.ch/sortiment/elektromechanische-bauelemente/mechanische-komponenten/montage-und-distanzteile/montage-und-distanzteile-metall.html

https://www.digikey.ch/de/products/detail/keystone-electronics/618/316540

https://www.distrelec.ch/de/montagewinkel-15mm-stahl-silber-packung-10-stueck-rs-pro-427991/p/30404248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

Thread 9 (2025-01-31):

Consider uing bajonet type connectors for umbilicals

brennmat, 2025-01-31:
Use connectors/sockets with bajonet locking instead of thread. Bajonet is more convenient.

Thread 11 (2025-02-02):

DHT socket PCBs

mbrennwa, 2025-02-02:
Consider making some small PCBs to fit on the DHT socket pins. The PCBs would hold the grid resistor and 4x screw terminals for the wire connections. They would also connect to the test sockets for the filament voltage. This would help with a cleaner build around the DHT sockets.

mbrennwa, 2025-02-09:
See also issue #16

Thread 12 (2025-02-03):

Positions of threads on chassis joints

mbrennwa, 2025-02-03:
Check (and fix if necessary): Drawing shows middle M3 hole at 135 mm. Is this correct?

mbrennwa, 2025-02-03:
fixed in drawing.

Closed 2025-02-03.

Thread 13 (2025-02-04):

Trimmers or parallel R to adjust CCS currents (input LTP, buffers)

brennmat, 2025-02-04:
Consider adding trimpots or simply an (optional) parallel resistor part to adjust/tweak the CCS bias currents in the LTP input stage and in the buffers for the DHT grid drive.

brennmat, 2025-02-04:
It's better to just determine the suitable resistor value for each specific DN2540 CCS by measurement before installing on the PCB. This way there will never be a loose wiper or accidental misadjustment of a trimmer.

--> add this to the documentation / build instructions

Closed 2025-02-04.

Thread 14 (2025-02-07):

Work out best method to determine the CCS sense resistor values

mbrennwa, 2025-02-07:
Try a small test jig to determine the R-sense value for the DN2540 CCSs in the amplifier before installing the parts on the PCB.

- [x] Determine parts values (voltage drop across 100 Ohm resistor gives current reading)
- [x] Determine suitable voltage for the test jig: 10 V and up is on the safe side
- [x] Add details to documentation

Closed 2025-02-08.

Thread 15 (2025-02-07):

Merge diverging docs

mbrennwa, 2025-02-07:
Merge diverging docs:

HA_documentation.tex.local
204c204
< \section{Build Notes, Bring-Up, and Initial Adjustments}
---
> \section{Bring-Up and Initial Adjustments}
210,211c210,211
< \item Assemble the power-supply chassis and boards. Install the boards and transformers in the power-supply chassis. Connect the primary windings of the transformers to the mains inlet and power switch in the chassis. Connect the power supply outputs to the umbilical sockets.
< \item Confirm proper connection of the power-supply chassis to mains earth.
---
> \item Assemble the power-supply chassis and boards. Install the boards, sockets, and transformers in the power-supply chassis. Connect the primary windings of the transformers to the mains inlet and power switch in the chassis. Connect the power supply outputs to the umbilical sockets.
> \item Confirm proper connection of all metal parts of the power-supply chassis to mains earth.
219,221c219,220
< \item Determine the CCS sense-resistor values that yield the targeted bias currents for the CCSs with the specific DN2540 parts used in the input LTP tail and in the DHT grid drivers. The setup shown in \figr{CCS_Rsense_jig} may be useful.
< \item Assemble the amplifier chassis, boards, and Coleman filament regulators. Install the boards in the amplifier chassis. Install the input-stage tubes, but do \emph{not} install the DHT tubes of the output stage yet. Do \emph{not} yet wire the ubilical sockets to the boards.
< \item Connect the umbilical cables between the power supply and the amplifier. Connect the amplifier chassis to the earth pin of the umbilical socket. Verify the connection of the amplifier chassis to the power-supply chassis and mains earth.
---
> \item Assemble the amplifier chassis, boards, and Coleman filament regulators. Install the boards and sockets in the amplifier chassis. Install the input-stage tubes, but do \emph{not} install the DHT tubes of the output stage yet. Do \emph{not} yet wire the ubilical sockets to the boards.
> \item Connect the umbilical cables between the power supply and the amplifier. Connect the amplifier chassis to the earth pin of the umbilical socket. Confirm the connection of all metal parts of the amplifier chassis to the power-supply chassis and mains earth. Make sure the XLR-1 pins are connected to the chassis.
223c222
< \item Connect the high-voltage supplies and GND from the umbilical socket to the amplifier board. Gradually ramp up the variac and confirm the correct DC bias of the input-stage tubes (plate voltages and currents) and the DC bias currents of the buffer stages.
---
> \item Connect the high-voltage supplies and GND from the umbilical socket to the amplifier board. Gradually ramp up the variac and confirm the correct DC bias of the input-stage tubes (anode voltages, CCS tail current) and the DC bias currents of the buffer stages. Depending on the specific characteristics of your DN2540 components, it may be necessary to adjust the bias points by selecting different values for the CCS sense resistors.
226,234d224
<
< \begin{figure}
< \begin{center}
< \includegraphics[height=0.2\textheight]{CCS_Rsense_circuit}
< \caption{Circuit to determine the sense-resistor value $R_{\textrm s}$ that yields the desired CCS current for a given DN2540 part ($Q_{\textrm x}$). Adjust $R_{\textrm s}$ until the voltage $V_{\textrm x}$ corresponds to the desired current. The test voltage $V_{+}$ should not be less than about \SI{5}{V}.}
< \figlabel{CCS_Rsense_jig}
< \end{center}
< \end{figure}
<

Closed 2025-02-08.

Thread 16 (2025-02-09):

Umbilical socket PCBs

mbrennwa, 2025-02-09:
Consider making some small PCBs to fit on the umbilical socket pins, linking the pins to the internal wiring using screw terminals for easier and cleaner installation of the wires.

(similar to issue #11)

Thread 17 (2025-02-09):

Make sure all chassis parts are in contact with mains earth (no paint on contact surfaces)

mbrennwa, 2025-02-09:
Make sure all chassis parts are in contact with mains earth. Make sure there is no paint on contact surfaces.

- [ ] Prevent/remove paint on inside of rear panel
- [ ] Prevent/remove paint at socket mounts

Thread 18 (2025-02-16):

Make more space for wires exiting between the DHT subchassis and the amp boards

mbrennwa, 2025-02-16:
Consider making the subchassis plate a bit more narrow. Could rotate the positions of the test sockets by 45°.

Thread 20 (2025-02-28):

Powersupply prototype build

brennmat, 2025-02-28:
Build powersupply prototype to go with the amplifier prototype:

- [ ] Design chassis
- [ ] Assemble PCBs
- [ ] Install and wire PCBs
- [ ] Test and confirm correct operation
- [ ] Test ripple on HV rails under amplifier load

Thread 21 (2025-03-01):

Amplifier chassis rear panel is a very tight fit

mbrennwa, 2025-03-01:
Remove about 0.5 mm or so from all outer edges and the holes for the XLR sockets. The thickness of the paint/coating on the side edges makes it too tight to fit.

Closed 2025-03-15.

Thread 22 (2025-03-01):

Bias point of DHT output tubes is sensitive to changes in mains voltage

mbrennwa, 2025-03-01:
Changes in mains voltage cause change in bias point of DHT output stage. This is likely caused by the PSU output (B- and B2- voltages), whereby their difference changes the grid bias voltage of the DHTs.

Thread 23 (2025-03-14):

Add connectors for power LEDs (amplifier chassis, PSU chassis)

brennmat, 2025-03-14:
Add connectors/pins to hook up the power LEDs in amplifier and PSU chassis:

- Amplifier chassis: add connector to umbilical board (not to amplifier boards, which are separate for both audio channels)
- PSU chassis: add connector to main PSU board

#16

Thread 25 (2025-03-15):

Add NTC and mains fuse to main wiring overview

mbrennwa, 2025-03-15:
In main overview drawing (kicad):

- Add mains fuse (see also #24)
- Add CL60 NTC inrush limiter

Closed 2025-03-15.

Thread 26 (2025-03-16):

HV PSU needs transformer with higher secondary voltage

mbrennwa, 2025-03-16:
Original design secondaries are slightly too low voltage to provide enough rectified DC voltage for the HV PSU dropout in the voltage reference.
Use a transformer with higher secondary AC voltages.

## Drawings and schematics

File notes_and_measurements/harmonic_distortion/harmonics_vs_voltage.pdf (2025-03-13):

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

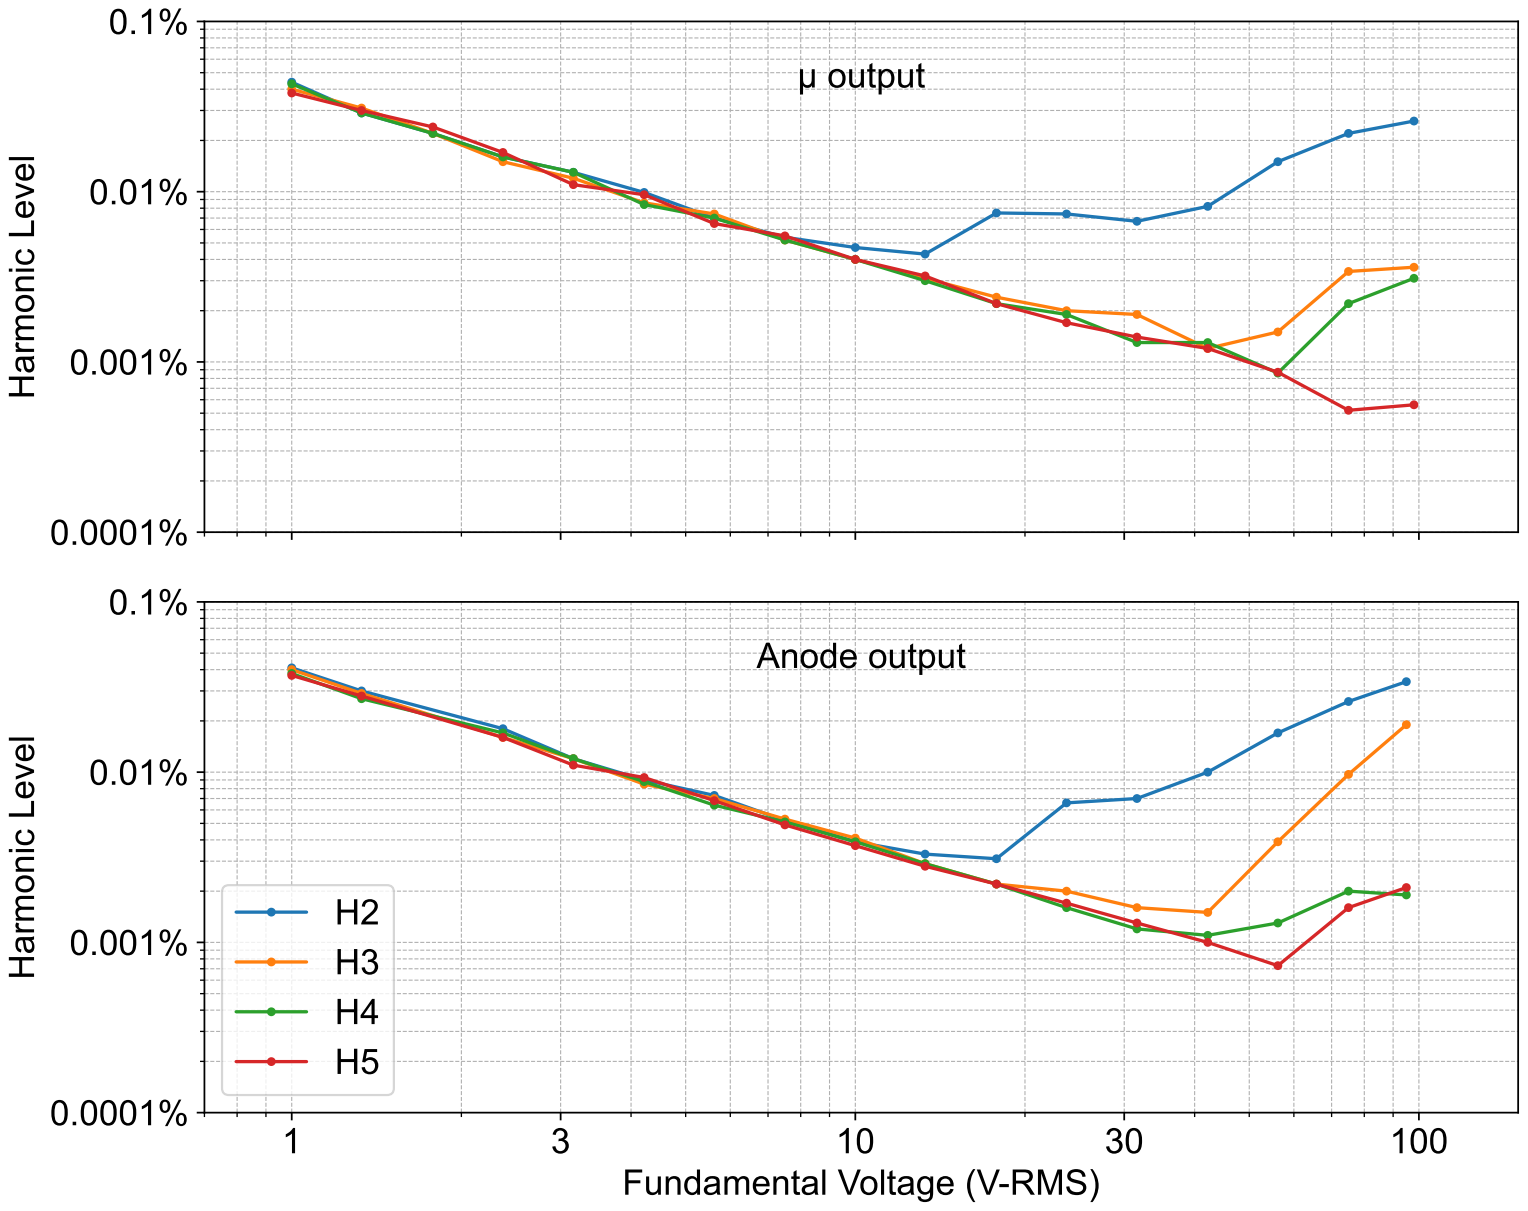
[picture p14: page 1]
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

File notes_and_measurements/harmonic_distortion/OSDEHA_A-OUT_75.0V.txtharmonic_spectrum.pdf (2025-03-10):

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

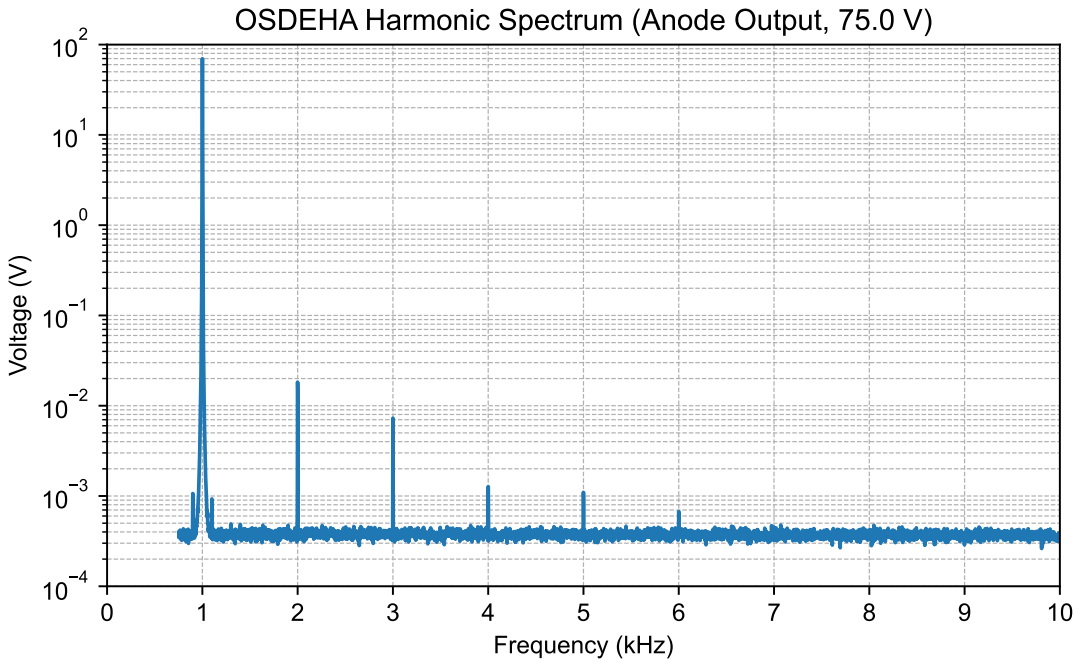
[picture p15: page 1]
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

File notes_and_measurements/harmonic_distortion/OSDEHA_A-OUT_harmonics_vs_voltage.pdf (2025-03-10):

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

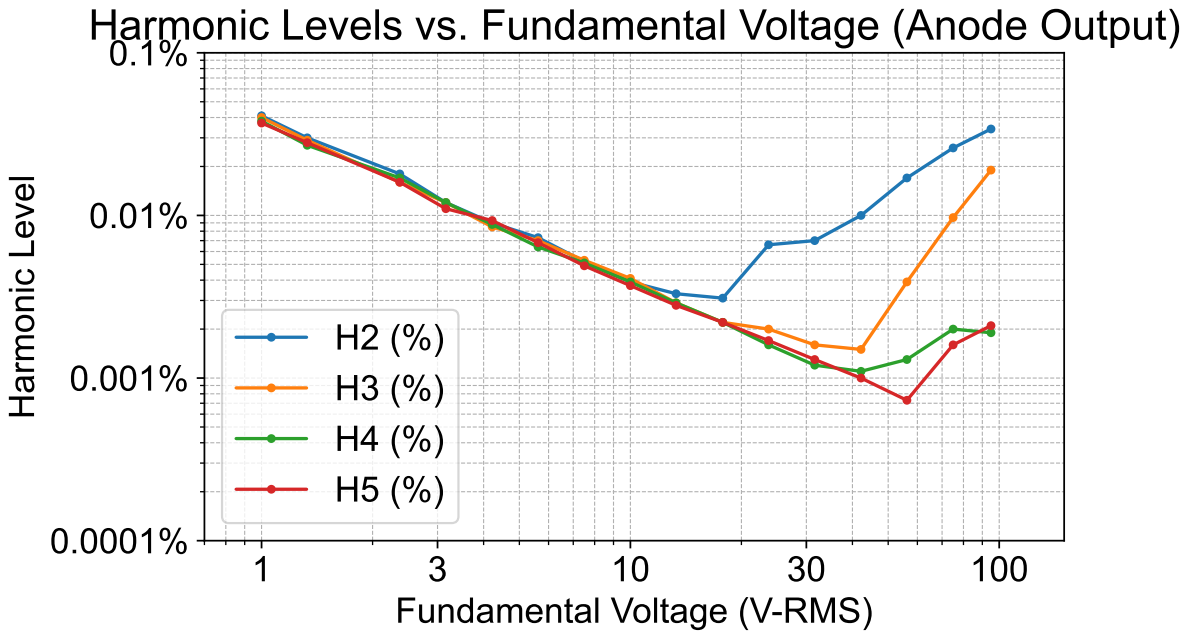
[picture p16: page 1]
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

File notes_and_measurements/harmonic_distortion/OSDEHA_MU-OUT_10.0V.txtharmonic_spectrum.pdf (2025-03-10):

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

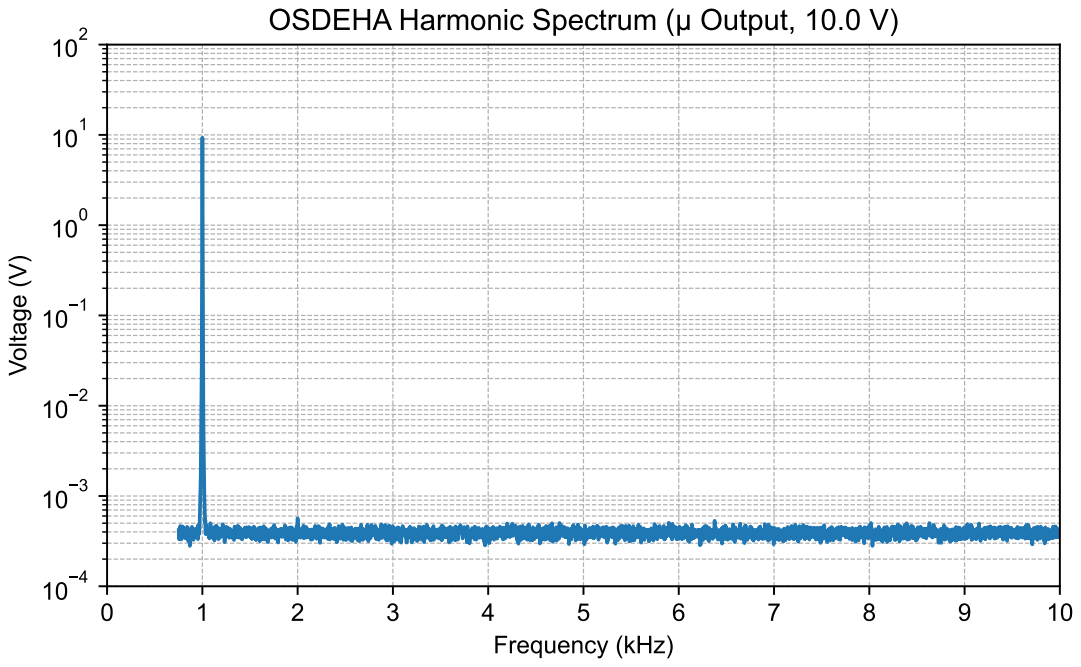
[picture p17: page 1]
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

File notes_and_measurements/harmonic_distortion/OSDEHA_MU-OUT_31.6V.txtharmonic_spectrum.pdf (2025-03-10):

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

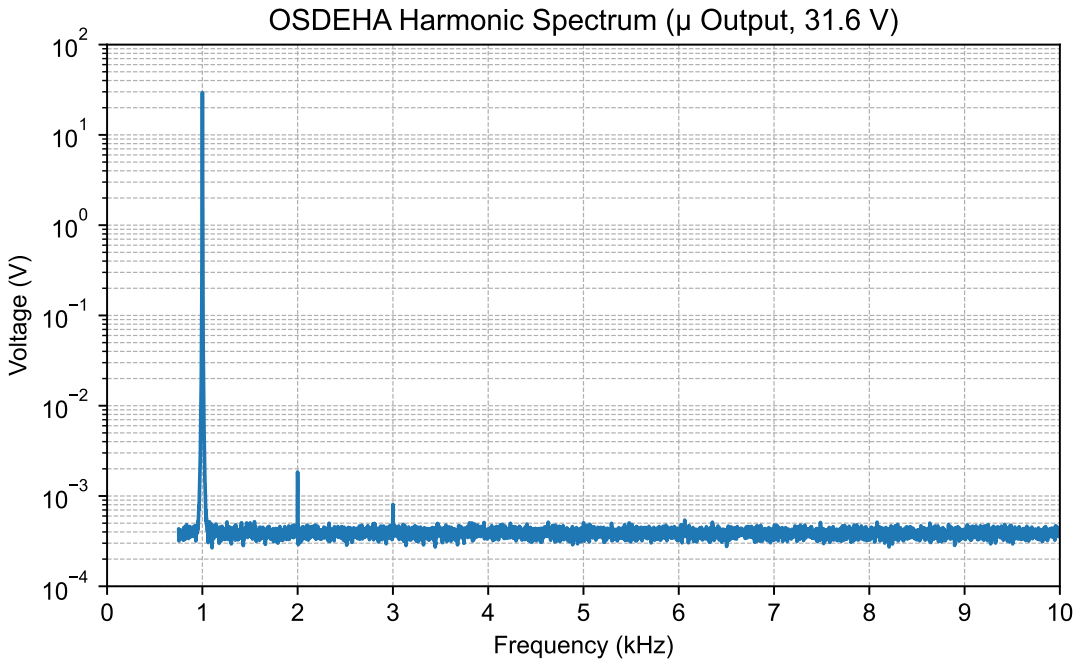
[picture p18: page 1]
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

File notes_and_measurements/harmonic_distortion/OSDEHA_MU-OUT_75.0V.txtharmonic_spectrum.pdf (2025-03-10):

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

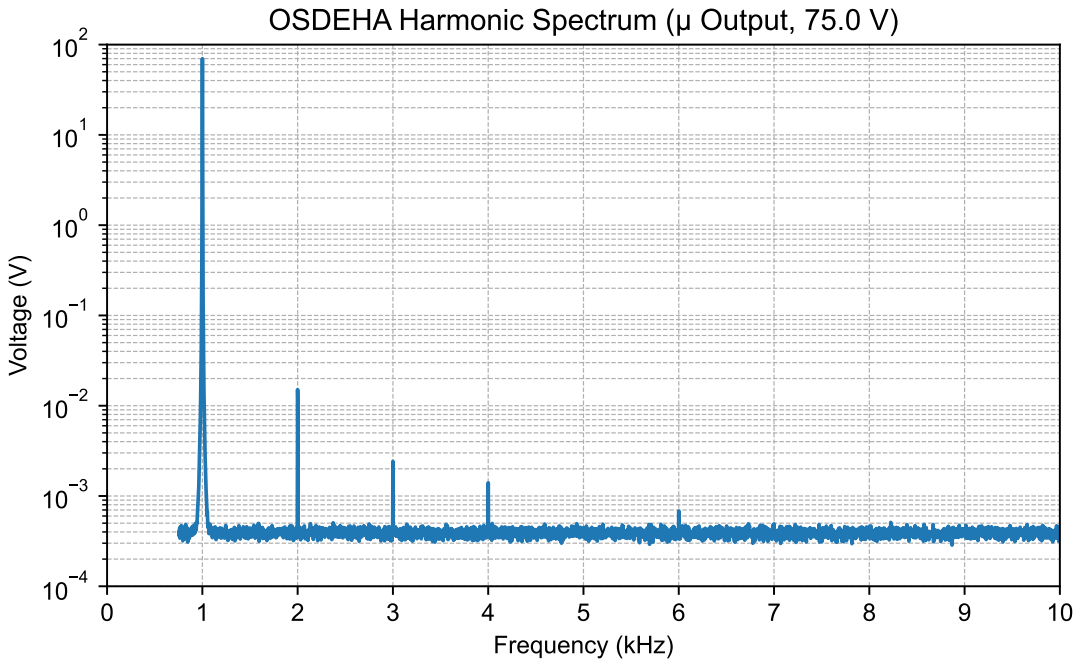
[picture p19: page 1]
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

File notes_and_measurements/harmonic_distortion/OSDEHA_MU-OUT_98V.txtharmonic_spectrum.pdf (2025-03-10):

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

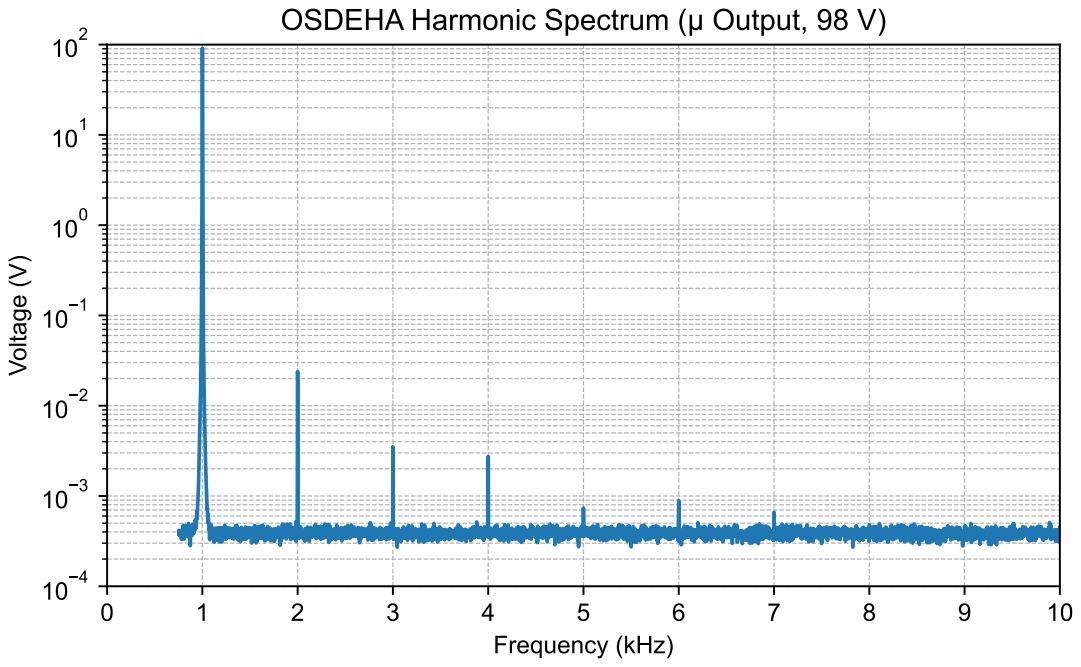
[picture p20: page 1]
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

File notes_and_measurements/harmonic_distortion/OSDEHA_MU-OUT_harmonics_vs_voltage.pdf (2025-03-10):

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

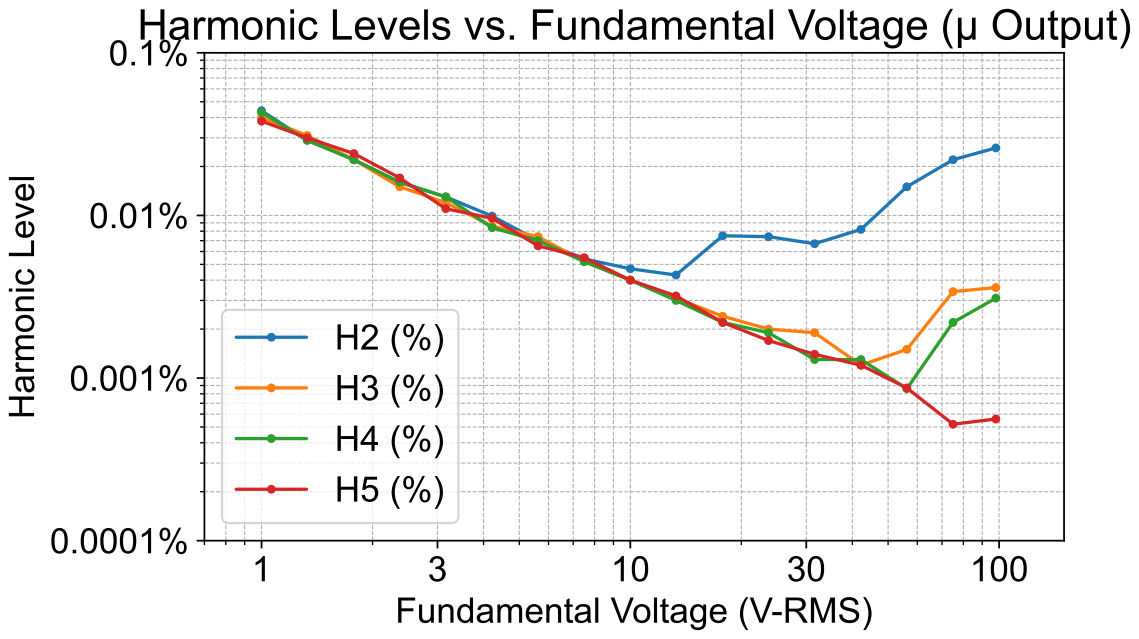
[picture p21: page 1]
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

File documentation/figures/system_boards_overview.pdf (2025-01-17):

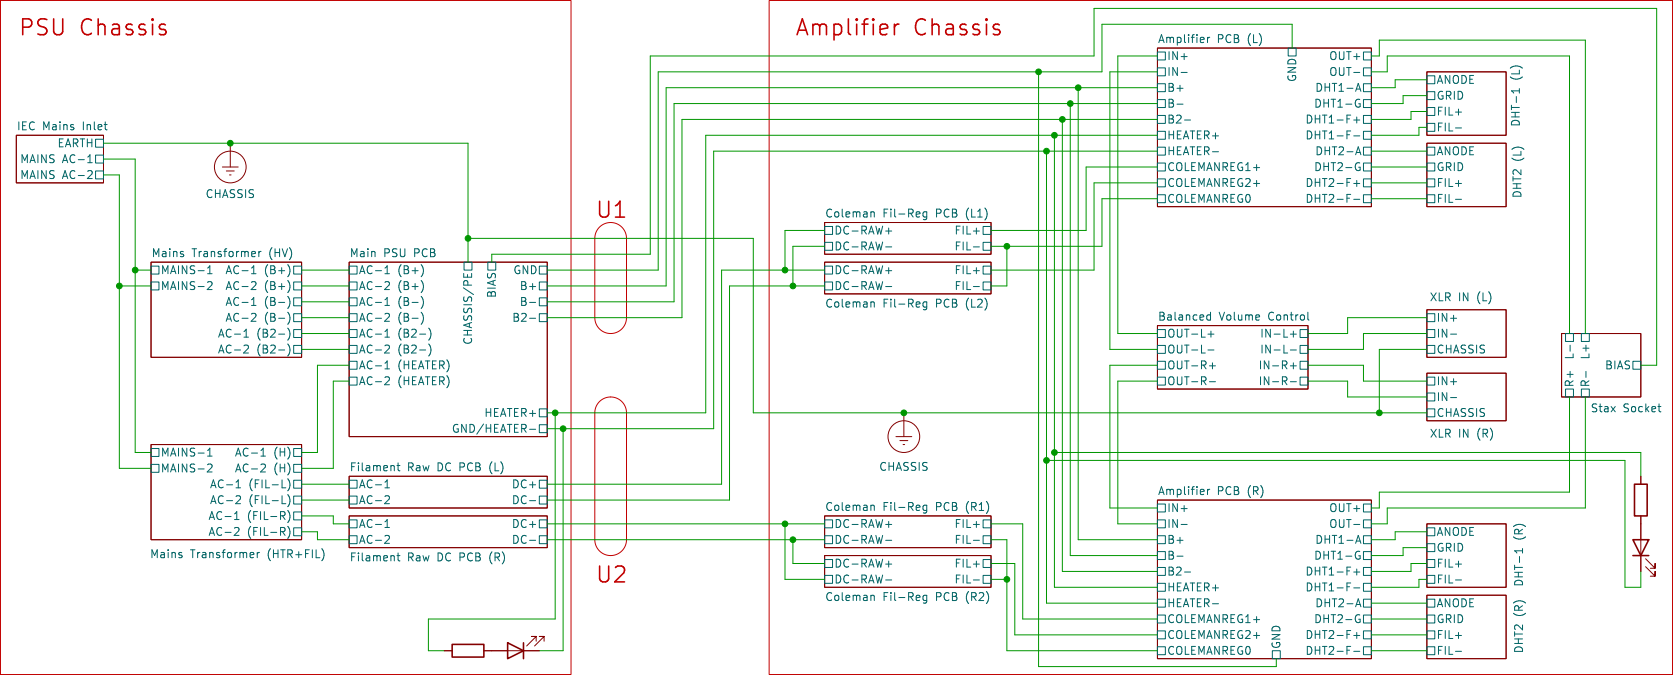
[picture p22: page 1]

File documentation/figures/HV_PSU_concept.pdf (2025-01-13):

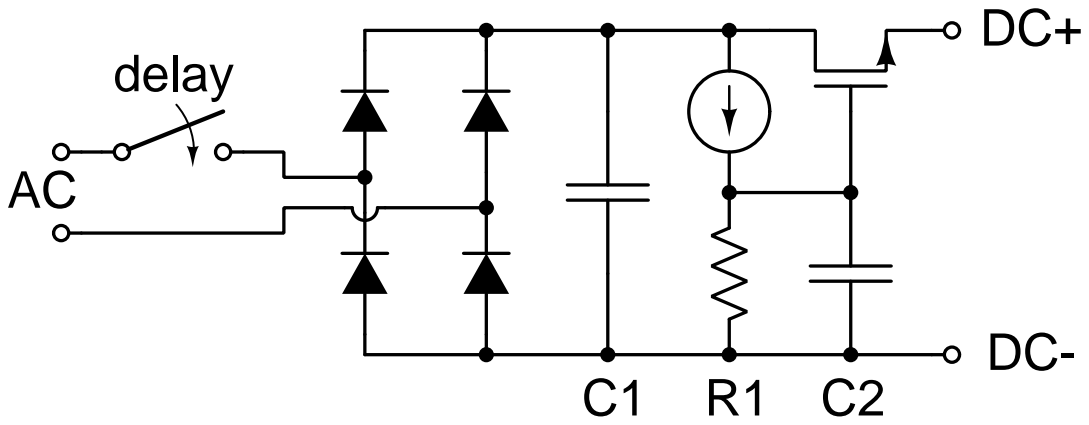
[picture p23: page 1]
delay

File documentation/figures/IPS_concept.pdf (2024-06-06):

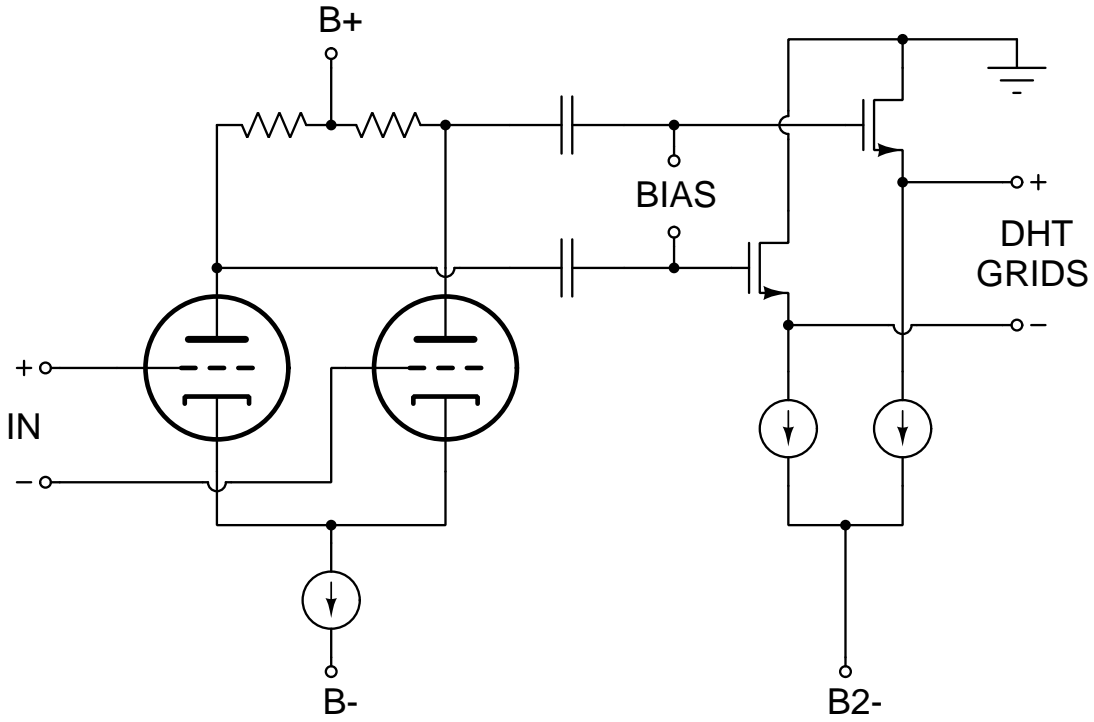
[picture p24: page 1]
BIAS; DHT GRIDS

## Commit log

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2024-01-10 more thoughts and data
    [DHT_list.ods]
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2024-01-15 update on Hybrid Mu and Moglia Gyrator ideas
    [DHT_list.ods]
2024-01-15 27 is INDIRECTLY heated
    [DHT_list.ods]
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2024-01-17 data and notes on input/driver tubes
    [DHT_list.ods, Millet_input_driver_pentodes.xls]
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2024-01-23 modified Colemand DHT filament regulator with negative filament referenced to GND
    [Coleman.kicad_sch]
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2024-01-25 LM4041 (noisy!) --> LM431
    [Coleman.kicad_sch]
2024-01-26 fixed error in filament supply
    [Coleman.kicad_sch]
2024-01-26 notes on DHT filament CCS
    [Coleman.kicad_sch]
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2024-01-27 separate Coleman DTH filament boards (not on main amp board) // work on gyrator load.
    [Coleman.kicad_sch, Gyrator.kicad_sch, OSDEHA_AMP.kicad_sch]
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2024-01-28 add buffer CCS sheet
    [buffer_CCS_load.kicad_sch]
2024-01-30 add heatsink notes, some footprints
    [Gyrator.kicad_sch, OSDEHA_AMP.kicad_sch, buffer_CCS_load.kicad_sch]
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2024-01-31 add grid leak resistor to 801A tube
    [OSDEHA_AMP.kicad_sch]
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2024-02-07 heater PSU, HV delay
    [OSDEHA_AMP.kicad_sch, OSDEHA_PSU.kicad_sch]
2024-02-07 coleman raw dc supplies
    [Gyrator.kicad_sch, OSDEHA_AMP.kicad_sch, OSDEHA_PSU.kicad_sch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]
2024-02-08 add coleman raw DC sheet schem
    [COLEMAN_RAW_DC.kicad_sch]
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2024-02-11 HV AC and cap voltages, HV filter caps to amp board
    [OSDEHA_AMP.kicad_sch, OSDEHA_PSU.kicad_sch]
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2024-02-13 MPNs and datasheet links
    [COLEMAN_RAW_DC.kicad_sch, OSDEHA_PSU.kicad_sch, hv_stabi.kicad_sch]
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2024-02-17 add Schrack relay with correct pin numbers
    [OSDEHA_PSU.kicad_pcb]
2024-02-17 fix relay symbol for correct pin numbers
    [OSDEHA_PSU.kicad_sch]
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2024-02-25 psu (del buffer, change output pass part)
    [COLEMAN_RAW_DC.kicad_sch, OSDEHA_PSU.kicad_pcb, OSDEHA_PSU.kicad_sch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]
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2024-03-01 move coleman reg psu to separate board
    [COLEMAN_RAW_DC.kicad_sch, OSDEHA_PSU.kicad_sch, powersupply_colemanreg.kicad_pcb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]
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2024-04-20 fix polarity of D2
    [OSDEHA_PSU.kicad_sch]
2024-04-20 fixed D2 polarity on PCB. Increased size of pads and holes for rectifier bridge in ground loop breaker.
    [OSDEHA_PSU.kicad_pcb]
2024-04-20 add vias for missing link between ground fills/zones
    [OSDEHA_PSU.kicad_pcb]
2024-04-21 lowered value of R30/R24/R18 from 1.5k to 1.0k, increased value of R3 from 973k to 1.1M
    [OSDEHA_PSU.kicad_sch]
2024-04-21 increased value of R1 and R2 from 797k to 866k
    [OSDEHA_PSU.kicad_sch]
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2024-04-22 increased pad size (external and internal) for the noval tube sockets
    [OSDEHA_AMP.kicad_pcb]
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2024-05-09 added Zener to clamp MOSFet VGS to 10 V
    [OSDEHA_PSU.kicad_pcb, OSDEHA_PSU.kicad_sch, hv_stabi.kicad_sch]
2024-05-10 added base resistor for NPN BJT in current limiter
    [OSDEHA_PSU.kicad_pcb, hv_stabi.kicad_sch]
2024-05-10 add dioded to outputs of HV supplies to prevent damage when loading outputs improperly
    [OSDEHA_PSU.kicad_pcb, hv_stabi.kicad_sch]
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2024-05-10 flip orientation of input tubes / pin allocations
    [OSDEHA_AMP.kicad_pcb]
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2024-05-12 improved + simplified wiring/connections to DHT filaments, improved pin/net labels
    [OSDEHA_AMP.kicad_pcb, OSDEHA_AMP.kicad_sch, OSDEHA_powersupply_DHTfil.kicad_pcb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]
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2024-05-13 revised HV protection parts (1N4007 diodes for output protection, Zener diodes on FETs, connection of current limiter). Improved widths of GND plane connections/pours.
    [OSDEHA_PSU.kicad_pcb, OSDEHA_PSU.kicad_sch, hv_stabi.kicad_sch]
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2024-05-13 work on RAW DC supply, various other cleanup things.
    [COLEMAN_RAW_DC.kicad_sch, OSDEHA_AMP.kicad_sch, OSDEHA_powersupply_DHTfil.kicad_sch]
2024-05-13 increased trimmer R value for time-delay switch of HV supplies to allow longer delay time
    [OSDEHA_PSU.kicad_pcb, OSDEHA_PSU.kicad_sch]
2024-05-13 use same clearance on filled zones for all PCBs
    [OSDEHA_PSU.kicad_pcb, OSDEHA_powersupply_DHTfil.kicad_pcb]
2024-05-14 test notes, notes in amp schematic (different parts?)
    [Gyrator.kicad_sch, OSDEHA_AMP.kicad_sch, buffer_CCS_load.kicad_sch]
2024-05-14 fixed error in amp board: CCS for buffer FETs need to connect to B2-, not to B-
    [OSDEHA_AMP.kicad_pcb, OSDEHA_AMP.kicad_sch]
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2024-05-14 attempt at nicer layout for HV supply (around the HV MOSFets and CCS voltage refs)
    [OSDEHA_PSU-B_Cu.gbr, OSDEHA_PSU-B_Mask.gbr, OSDEHA_PSU-B_Paste.gbr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]
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2024-05-15 fixed DN2540 and AOT pinout in buffer + CCS from DGS to GDS -- still need to apply the fix on the PCB!
    [OSDEHA_AMP.kicad_sch]
2024-05-15 fix pinouts of DN2540 and STF buffers on amp PCB board (Q3, Q4, Q9, Q10)
    [OSDEHA_AMP.kicad_pcb, OSDEHA_AMP.kicad_sch, buffer_CCS_load.kicad_sch]
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2024-05-15 minor edit on PCB for improved GND plane pour
    [OSDEHA_AMP.kicad_pcb]
2024-05-16 change BC550 (out of production) to 2N3904. Turn off visibility of part values in Kicad display of PCB.
    [OSDEHA_PSU.kicad_pcb, hv_stabi.kicad_sch]
2024-05-22 add missing sch file
    [OSDEHA_powersupply_DHTfil.kicad_sch]
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2024-05-26 adjust values of R15 and R20 by measurement of Vbias
    [OSDEHA_AMP.kicad_sch]
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2024-06-01 fixed pinout of Q6 and Q8 in schematic
    [Gyrator.kicad_sch]
2024-06-01 fixed pinout of Q6 and Q8 on PCB
    [OSDEHA_AMP.kicad_pcb]
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2024-06-03 ideas on what might be wrong with HV voltage ref CCS, 2N3904 pinout backwards?
2024-06-03 fixed pinout of Q6/Q10/Q14 on PCB
    [OSDEHA_PSU.kicad_pcb, hv_stabi.kicad_sch]
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2024-06-08 changed R13 and R18 from 1M to 100k in schematic and PCB
    [OSDEHA_AMP.kicad_pcb, OSDEHA_AMP.kicad_sch]
2024-06-08 revise R values in schematic and PCB files. Expand test/design notes.
    [Gyrator.kicad_sch, OSDEHA_AMP.kicad_pcb, OSDEHA_AMP.kicad_sch]
2024-06-10 change R20 from 300R to 2.1k to prevent current limiter from blowing up if output is shorted and C12 has to drain through Q6
    [hv_stabi.kicad_sch]
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2024-06-12 avoid Gyrator term
    [hv_stabi.kicad_sch]
2024-06-13 add version info to silk screens (AMP + HV PSU)
    [OSDEHA_AMP.kicad_pcb, OSDEHA_PSU.kicad_pcb, hv_stabi.kicad_sch]
2024-06-13 add gate stopper for CCS FET in output stage / mu follower
    [Gyrator.kicad_sch, OSDEHA_AMP.kicad_pcb, hv_stabi.kicad_sch]
2024-06-13 add version label to DC raw supply (schematic and PCB)
    [OSDEHA_powersupply_DHTfil.kicad_pcb, OSDEHA_powersupply_DHTfil.kicad_sch]
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2024-06-14 add Zener clamp to DHT grids to prevent too much positive grid voltage
    [OSDEHA_AMP.kicad_pcb, OSDEHA_AMP.kicad_sch]
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2024-06-14 workaround for KiCad net labels confusion around the DHT tubes (due to off-PCB parts)
    [OSDEHA_AMP.kicad_pcb, OSDEHA_AMP.kicad_sch]
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2024-06-16 test notes (oscillation)
    [Gyrator.kicad_sch]
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2024-06-16 revert grid stoppers to 100R
    [OSDEHA_AMP.kicad_sch]
2024-06-16 add diode to protect FET drain pin in buffer CCS from negative drain-source voltage (that may happen in case of large AC swings).
    [OSDEHA_AMP.kicad_pcb, buffer_CCS_load.kicad_sch]
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2024-06-23 Add protection diode to buffer CCS, PCB fixes
    [OSDEHA_AMP.kicad_pcb, buffer_CCS_load.kicad_sch]
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2025-01-03 chassis, make sure same cutter tool is used for all objects on top plate cutouts
    [amp_chassis_layout.dxf]
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2025-01-17 fixed hole position
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2025-01-17 Added STL file for Stax socket (chassis mount), designed by chinesettawong@diyAudio
    [Stax_female_socket_chinsettawong_diyAudio.stl]
2025-01-17 fix issue #1: consistent screw holes
2025-01-17 fix issue #3: different M3 / transistor mount holes for LEFT and RIGHT heatsinks
    [heatsink_drillplan.dxf]
2025-01-18 added missing holes, confirmed hole positions on left/right heatsinks / issues #3 and #6
    [heatsink_drillplan.dxf]
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2025-01-19 fixed issue with test-socket holes
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2025-01-30 add hole for screw to attach Earth connection (issue #2)
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2025-02-02 add missing file
    [OSDEHA_PSU.kicad_sch]
2025-02-03 fixed thread position (issue #12)
    [joints.dxf]
2025-02-04 doc: CCS sense resistor values, issue #13
    [Gyrator.kicad_sch, OSDEHA_AMP.kicad_pcb, OSDEHA_AMP.kicad_sch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]
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2025-02-08 Stepped vol ctl resistance level 100k --> 10k on amp schematic
    [OSDEHA_AMP.kicad_sch]
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2025-03-02 revise DHT grid bias to use a Zener for voltage reference relative to B- rail
    [Gyrator.kicad_sch, OSDEHA_AMP.kicad_pcb, OSDEHA_AMP.kicad_sch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]
2025-03-04 fix errors in BIAS HV supply
    [Gyrator.kicad_sch, OSDEHA_AMP.kicad_sch, OSDEHA_PSU.kicad_pcb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]
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2025-03-09 repeated measurements with correct wiring #19
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2025-06-02 Revert "add Gerbers AMP V20250304"
    This reverts commit 6115ab966fcf3261c7cd48dd2866a10d8f8f410e.
    [OSDEHA_AMP.kicad_pcb]
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
